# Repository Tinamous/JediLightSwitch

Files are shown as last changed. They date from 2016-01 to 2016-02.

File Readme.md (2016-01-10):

Jedi LightSwitch
================

The Jedi Light Switch is a home automation light switch which responds to the Jedi wave or touch(1). It aims to bring the humble wall switch into the modern WiFi lighting era.

1) Automation of modern WiFi lamps (LIFX/Hue) doesn't work if the lamp is switch off at the wall switch.
2) Existing switch may not work as expected for visitors with WiFi bulbs. Often the switch is on but the light off.
3) Switching the lights on/off via an app is annoying.
4) The wall switch may be difficult or impossible to replace with a automation friendly version. (Excludes the Jedi Lightswitch :-) )
5) The existing switch is single use, it switches on or off the main light. In a modern house their are many things this switch can be doing.

The Jedi Light Switch is PCB based with a custom 3D printed enclosure. It is powered by a Particle Photon which uses WiFi and optionally cloud services (i.e. IFTTT.com / Tinamous.com) to control and monitor the room environment.

The Photon may be user programmed so the switch may be heavily customised as desired, even OTA after installation. Likewise lighting control via IFTTT may be modified at will.

As well as acting as a switch it also acts as a room sensor with built-in temperature, humidity and light level measurements which may be used for further automation tasks.

Proximity detection allowing the sensing if somebody is close to the switch. (e.g. Switch the lights on in the room if they are not and somebody is close to the switch as they are probably about to try and switch them on anyway).

Two LEDs controlled by the Photon give the immediate feedback (cloud sevices may take a few seconds to perform the apporpiate operations), these LEDs may also be internet controlled to draw attention to something (i.e. the doorbell ringing).

Why:
----
If you have LIFX or Hue lights they stop working once somebody switches them off at the wall switch which can ruin your automation plans. The Hue has a small switch however the LIFX lights rely on 3rd party products for switching, both suffer from our built-in tendandy to switch the light off at the switch as we leave the room. Neither lights work so well when that happens! Neither Hue or LIFX switch options are immediatly obious that they should be used in preference to the wall switch. Nobody wants to have to train their guests how to switch the lights on or off.

Imaging the scene. You walk into your room, the lights are off but the light switch is on.
* Option 1: Switch the light switch off then on again. This works a charm (but only for the main light).
* Option 2: 
** Find your phone (hopefully it's not somewhere in the dark room you are walking into)
** Unlock your phone
** Launch the LIFX application
** Wait whilst the LIFX applicaiton loads
** Try not to trip or walk into anything as you've continued to walk whilst working your phone in the darkened room
** Scroll to the bulbs or scene you wish to set
** Select the bulbs or scene
** Hopefully the lights respond first time, if not wait a bit and try again
** Put phone away
** Think how great it is you can control your lights from your phone...

Leaving a room:
---------------
Nobody likes to leave the lights on in rooms that are unused or when you go out.....

Imaging you leave the room.
* Option 1: Flick the light switch to switch the light off (goodbye automation).
* Option 2: Find your phone, unlock your phone (you see where this is going).

Neither of these senarios are great. You could replace or remove the light switch...

The Light Switch Problem:
-------------------------
* In the UK we have a different style and voltage requirement for light switchs compared to USA, hence home automation products are slow (if ever) to reach the UK market.
** This is not helped by the need for a CE mark which is slow and expensive.
** Often the switches that are available are extreamly cheap (I've had 5x £30 switches fail when the incandecent bulb blew).
* Most HA light switches require a minimum of 25mm backing box. A lot of UK homes use a 15mm box which either means you need to pad the switch out on the wall (ugly) or replace the box (painful).
* A lot (almost all) HA light switches require "3 wire" configuration. Live, Neutral and switch return. Most UK homes have only 2 wire switches (Live and return).
* Not everybody wants to play with the electrics to get a fancy light switch fitted or pay for an expensive electrician.
** If it's a 2 wire replacement this isn't too difficult, changing the 2 wires to 3 and/or replacing the backing box are a big job.
* If you rent chances are you are not allowed to replace the light switch anyway. Who wants to get thrown out of their rented accomodation for a bit of home automation goodness!
* Switching the lights off at the light switch ruins automation.
* The light switch generally only controlls the main light, occasionally wall lights.
* Switching the wall switch on or off doesn't tell your home automation system that the action has happened so no further actions can happen based on that.
* Theirs no intelligence in the on/off of the humble wall switch. If you walk into a room when you're still half asleep having the light come on at 100% brightness is painful.

The Solution:
-------------
The Jedi Light Switch is designed to remove those problems through a two part solution. The main part is the touch and gesture sensitive WiFi based switch PCB, the second is the enclosure.

The switch and enclosure are designed to be simple to install, no re-wiring required (except for external USB power), a direct replacement for the humble wall switch whilst leaving the switch in place, just hidden behind some sexy technology.

The current enclosure is designed to fit over a UK light switch (sorry rest of the world, It may work in Europe, it certainly won't fit over USA switches). 

The enclosure is 3D printed in two parts:

1) The base. This has an overlap area that fits between the wall and the existing switch to secure the base in place and only requires the switch to be loosened and not removed.
** To fit loosen the screws on the light switch slightly so that the switch comes forward about 2mm.
** Slide the base down the wall so the back fits between the wall and the switch until the top of the switch is as close to the top of the base as it can go.
** Tighten the switch screws, ensuring the enclosure is level. This clamps the base part to the wall. No other fixing is required.
2) The cover:
** This is optional. You may if you wish attach the switch PCB via glue or screws to the base and be done.
** The cover gives a nicer finish to the switch whilst also providing mechanical fixing of the PCB within the base. It may be printed in any colour you can get the 3D filament or resin for, although clear works well.
** Optional: You may also print on a clear "acetate film" to fit between the cover and the PCB with a nice pattern or design over the touch sensor.
** The cover simply slides over the base with the PCB in the middle and stays in place by friction making it easy to remove should you need access to the actual wall switch.

Other Advantages:
* Use of gesture to switch the lights on would work well in dirty/wet areas (e.g. the kitchen) where you may not wish to touch something (e.g. you've half way through cooking chicken).
* The switch supports up, down, near and far waves as well, these may be used to dim the lights, control additional (hall/landing) lighting or something else.
* You don't actually need an existing light switch. The case could be directly attached to the wall or something else to provide easy additional lighting points.
* Other than a USB power pack and WiFi no other external parts are required (no Hub, no dedicated lighting wiring, no ......, not even screws or double sided sticky tape)
* You don't have to be British (but it helps). The switch enclosure and PCB are sized to cover a UK light switch, however as they can be used in stand-alone mode they don't have to be used with a UK switch.
** The SCAD design for the enclosure is provided which may be modified to fit other requirements.
* Intellegent:
** The lights could be dimmed to brightness greadually, especially if the switch knew the room was very dark previously.
** or set to automatically switch off or dim the lifhts after 2 hours.
** or the air-con switched on if the room is hot and humid and the lights have just been switched on (or off).
** the curtains could be closed automatically when the lights are switched on.
** the whole house lights could be switched off if the hall light was switched off (and vica versa, house lights switched on when it's dark when hall/door switch is switched on).

Limitation:
-----------

* Currently requires external USB 5V DC power as the Photon is relativly fairly power hungry device (i.e. using WiFi). Even if a battery was fitted it would require a fair size and to be topped up regularly particularly if the switch is required to respond to network actions (e.g. light LEDs, update firmware etc.).

* Lack of a traditional switch mechanism which may confuse guests. Hopefully the touch ability would be enough to make up for this.

* Cloud services can be slow. Using Photon -> Particle.io -> IFTTT -> LIFX.com -> LIFX bulb can be seconds in the trip which is not idea for a light switch. In this time a new user may have told the switch to switch on/off/on/off/on etc a number of times.

Future upgrades:
----------------

Planned for V1.1:
* 2 LEDs in the bottom corners to match the top so each corner has an LED.
* Back lighting. Adding more LEDs to project backwards to light up the enclosure (works best for clear enclosures). Ideally NeoPixel type so they can be controlled from 1 wire and have a range of colour / intensity controlled.

Future posabilities:
* Split/Dual touch sensor pads so that it works for hall/landing lights (up/down) or duel lighting modes in a room (main/wall lights).
* RS485 interface, supply 5V to Photon from a RS485 with 12V house wired RS485 network, interface with other RS485 HA devices and provide a more reliable connection and power.
** This is easier then putting a PoE Ethernet connection on the switch.
* Battery + charger
* Improved interrupt's that can be used to wake the Photon (currently 2 interupts, one high and one low which can't both be used to wake the Photon) to improve battery life.
* Buzzer
* IR Sender to allow the switch to send out instructions from automation requests (e.g. telly on) or relay the signal from room to room.
* IR Receiver to allow remove control of the switch and/or transmission from room to room.
* Microphone (to decect noise levels rather than listen).
* PIR sensor
* Improved temp/humidity sensor for one of the new Bosch line with BP and gas sensing as well.

License:
--------
Licensed under Creative Commons ShareAlike 4.0 https://creativecommons.org/licenses/by-sa/4.0/

Restrictions: May not be used to control lighting on a death star.

Notes:
------
1) Also responds to non-Jedi waves and touch. Not to be used where control by non-Jedi personel is restricted.

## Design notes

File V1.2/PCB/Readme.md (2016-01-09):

Jedi LightSwitch PCB.
=====================

Licensed under Creative Commons ShareAlike 4.0 https://creativecommons.org/licenses/by-sa/4.0/

PCB Fabrication by OSH Park.
PCB: <TODO: Insert PCB link>

PCB Stensil by OSH Stencil (https://oshstencils.com/).

PCB Assembly Notes:
-------------------
APDS-9960 and HTU21D are tricky components to solder onto the board. The switch may be used without them if you wish to not solder them and prefer to use touch only.

Use either a hot air gun for solder reflow or reflow oven for the top layer. Use a stencil from OSH Stencils and place U1/U2 (APDS-9960 and HTU21D) carefully. 

Using a low flow and a temperature appropriate for the solder paste heat the board around U1/U2 bringing until the solder melds. Allow a little longer for U1 as the solder is not visible.

The bottom of the board should be hand solderered to prevent U1/U2 dropping off. Most parts are 1206 or 0805 and not overly difficult. U4 (AT42QT1010) is a little difficult but excess solder can be removed with solder wick if needed.

The value of C4 may need to be adjusted to increase/reduce sensitivity. 10nF was found to be to little. 68nF was overly sensitive.

The value of R5/R6 should be selected based on the required brightness of the LEDs and the LED selected.

Resources:
----------
SparkFun Eagle Library and breakout boards used under CC-SA.

SparkFun Eagle Library: https://github.com/sparkfun/SparkFun-Eagle-Libraries

SparkFun APDS-9960 breakout: https://www.sparkfun.com/products/12787
SparkFun HTU21D breakout: https://www.sparkfun.com/products/12064
SparkFun AT42QT1010 breakout: https://www.sparkfun.com/products/12041

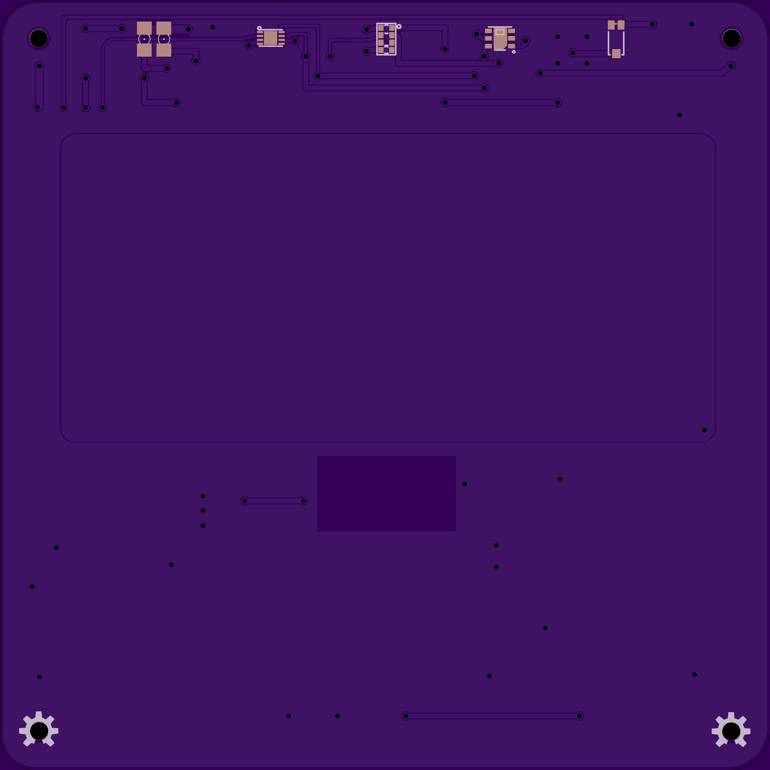
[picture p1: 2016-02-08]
V1.2/PCB/JediLightSwitch-1.2-Top.png

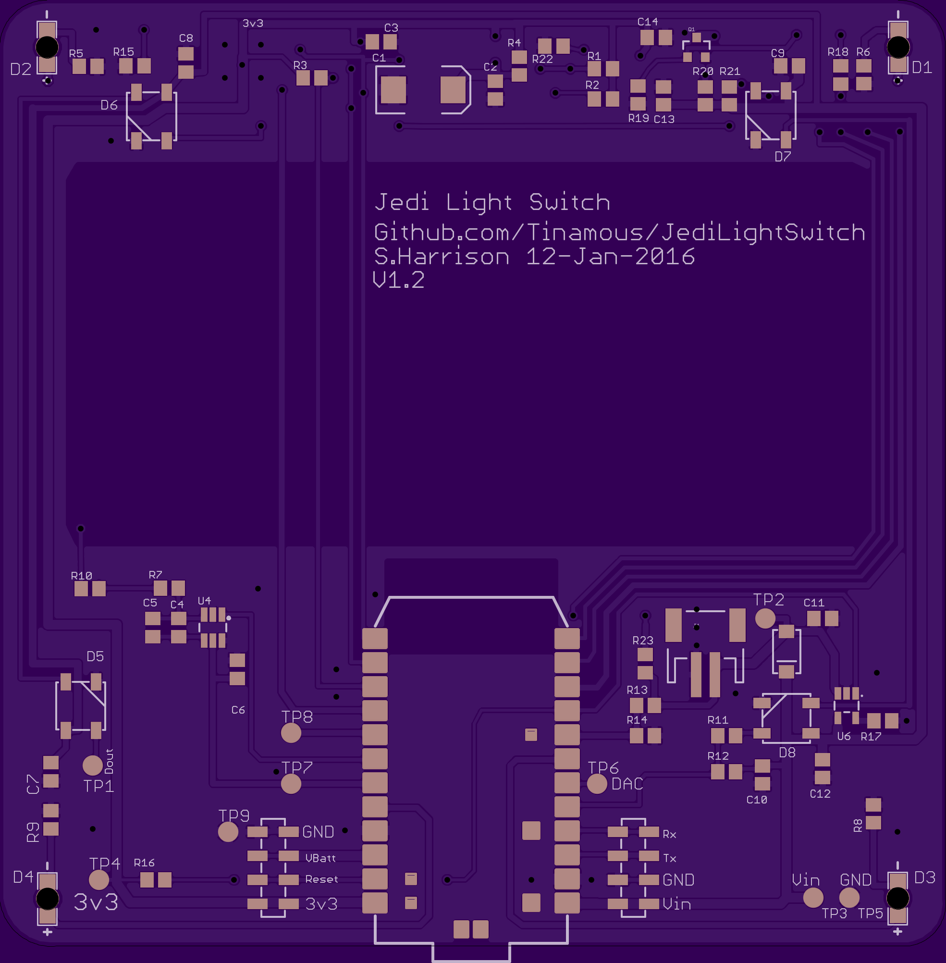
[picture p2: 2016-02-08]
V1.2/PCB/JediLightSwitch-1.2-Bottom.png

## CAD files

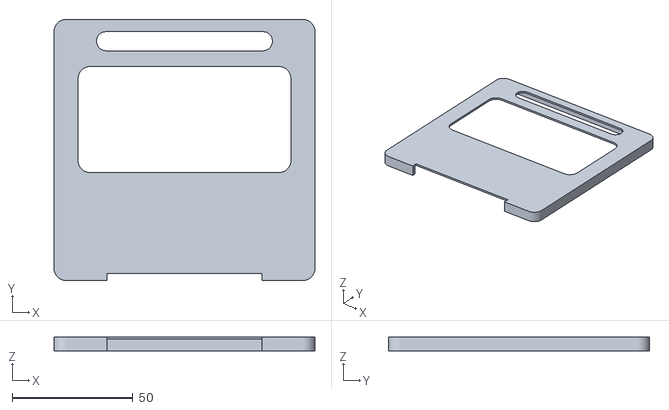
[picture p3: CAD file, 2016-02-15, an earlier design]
V1.1/Enclosure/Cover-5mm-V1.2.stl
108.2 x 108.2 x 6.00

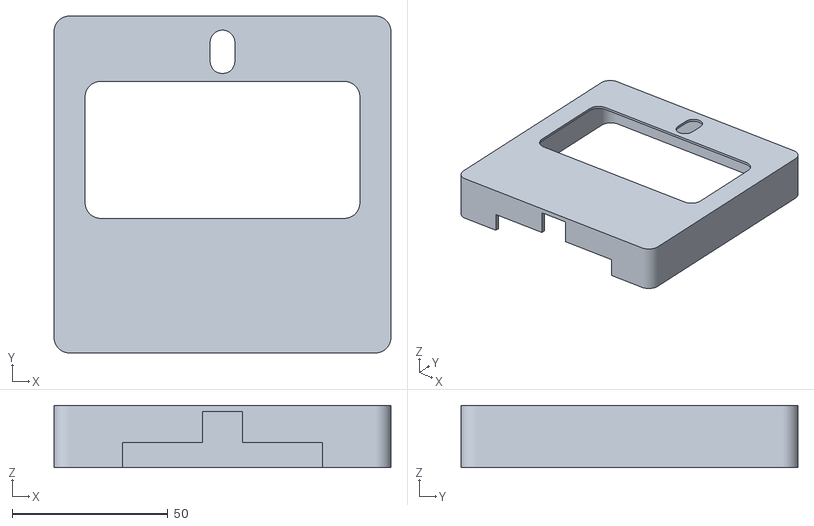
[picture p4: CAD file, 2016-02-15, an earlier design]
V1.1/Enclosure/Cover-19mm-V1.1.stl
108.2 x 108.2 x 20.0

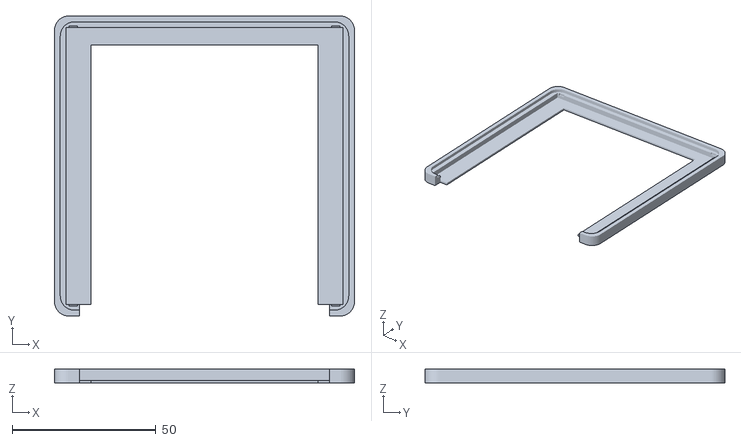
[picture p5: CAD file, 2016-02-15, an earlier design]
V1.1/Enclosure/Base-5mm.stl
104.2 x 104.2 x 5.00

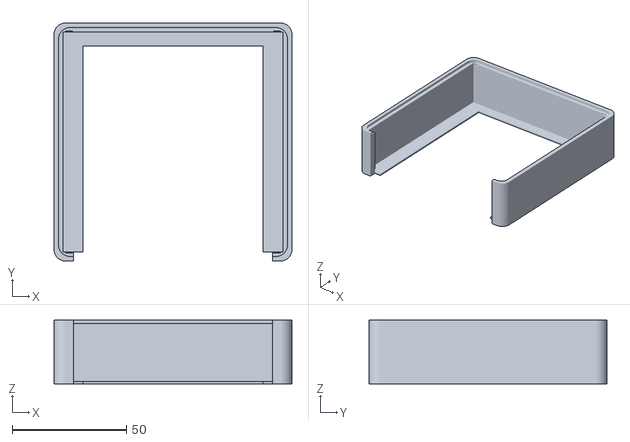
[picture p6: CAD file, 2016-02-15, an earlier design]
V1.1/Enclosure/Base-28mm.stl
104.2 x 104.2 x 28.0

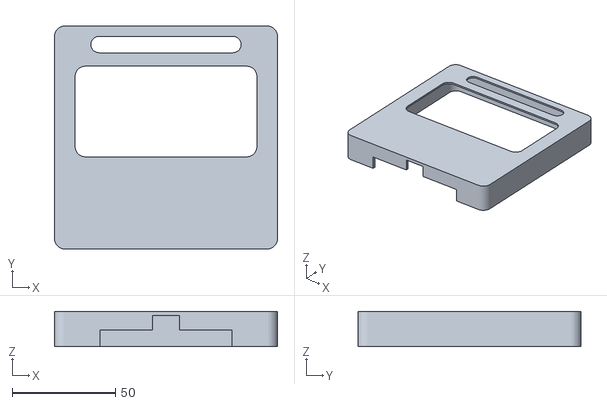
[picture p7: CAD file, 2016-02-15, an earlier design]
V1.1/Enclosure/Cover-16mm-V1.2.stl
108.2 x 108.2 x 17.0

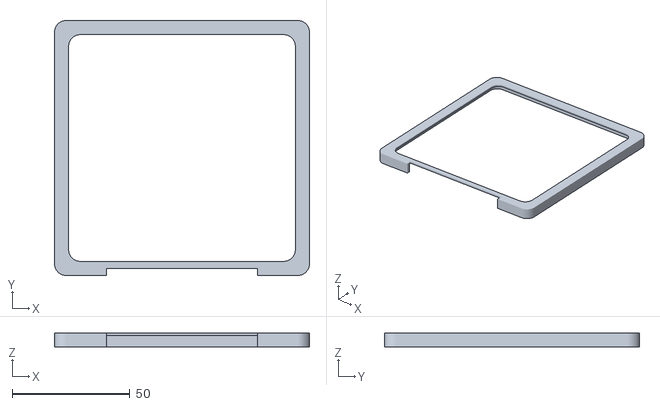
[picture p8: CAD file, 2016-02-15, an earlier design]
V1.1/Enclosure/Cover-5mm-minimal.stl
108.2 x 108.2 x 6.00

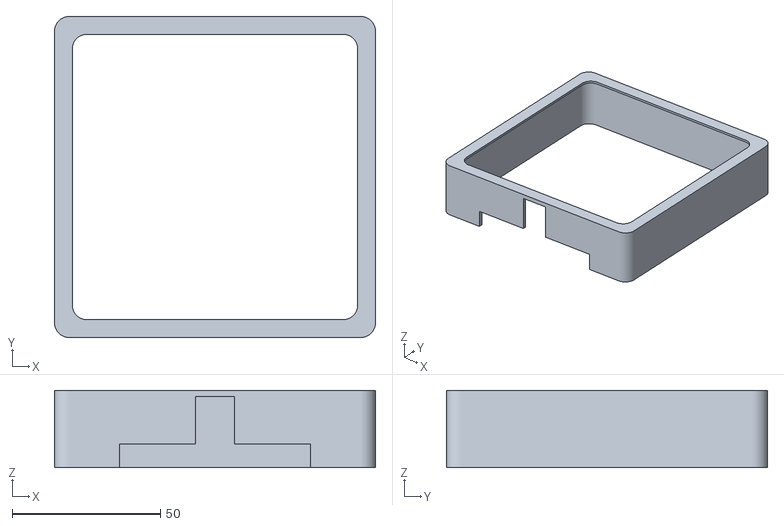
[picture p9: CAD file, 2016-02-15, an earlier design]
V1.1/Enclosure/Cover-25mm-minimal.stl
108.2 x 108.2 x 26.0

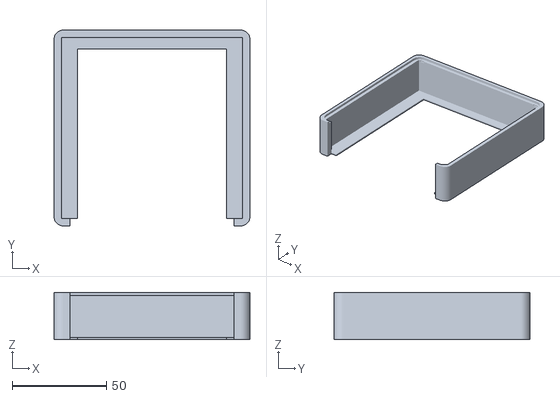
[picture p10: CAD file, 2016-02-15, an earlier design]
V1.1/Enclosure/Base-25mm.stl
104.2 x 104.2 x 25.0

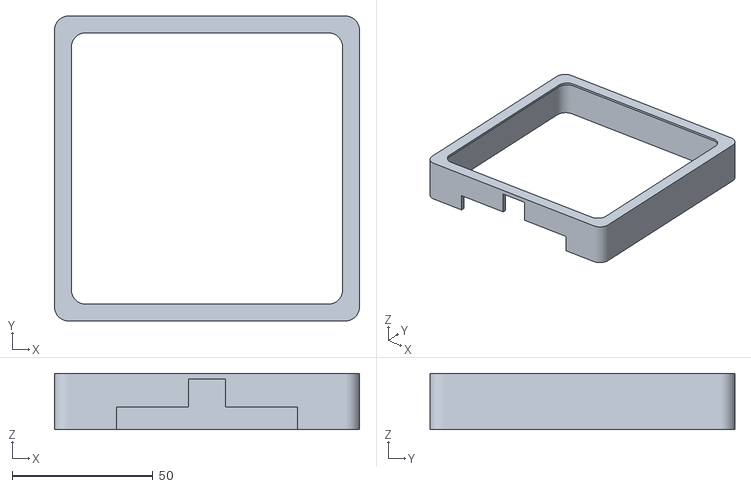
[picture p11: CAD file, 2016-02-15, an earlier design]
V1.1/Enclosure/Cover-19mm-minimal.stl
108.2 x 108.2 x 20.0

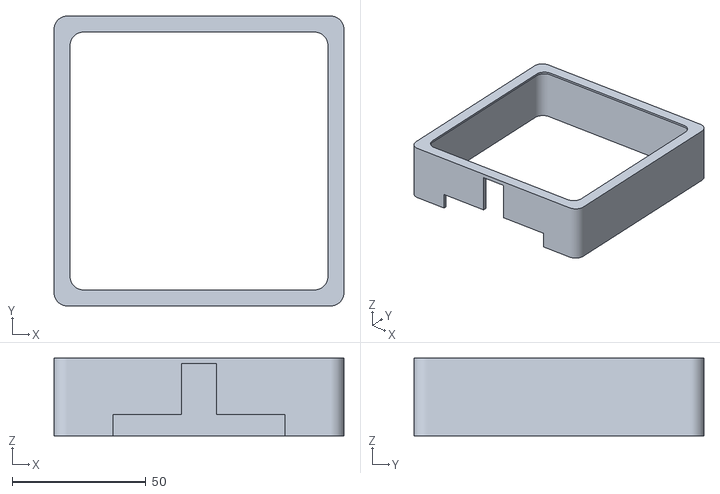
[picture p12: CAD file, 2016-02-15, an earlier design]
V1.1/Enclosure/Cover-28mm-minimal.stl
108.2 x 108.2 x 29.0

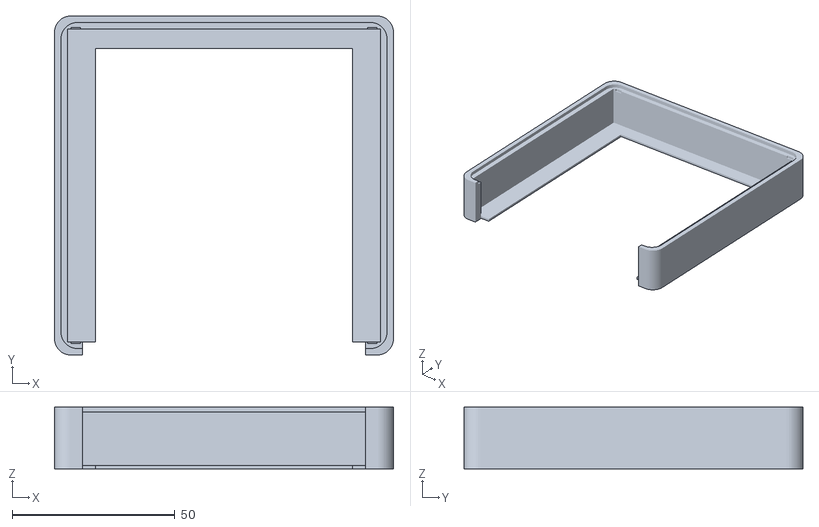
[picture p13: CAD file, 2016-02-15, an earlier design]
V1.1/Enclosure/Base-19mm.stl
104.2 x 104.2 x 19.0

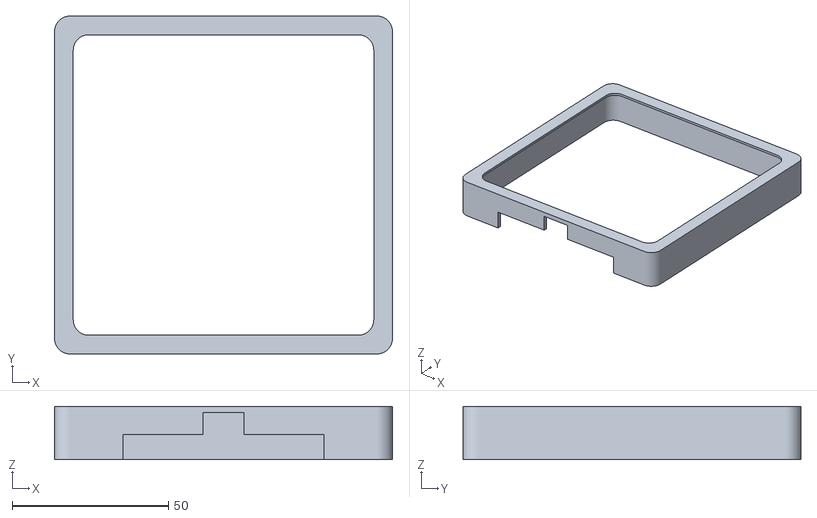
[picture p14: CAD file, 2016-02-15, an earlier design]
V1.1/Enclosure/Cover-16mm-minimal.stl
108.2 x 108.2 x 17.0

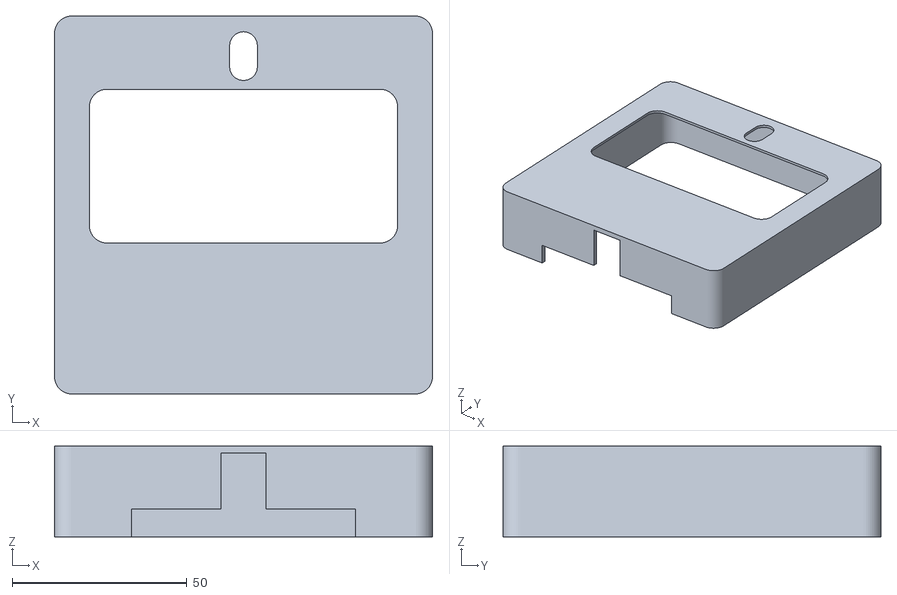
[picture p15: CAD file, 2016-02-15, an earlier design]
V1.1/Enclosure/Cover-25mm-V1.1.stl
108.2 x 108.2 x 26.0

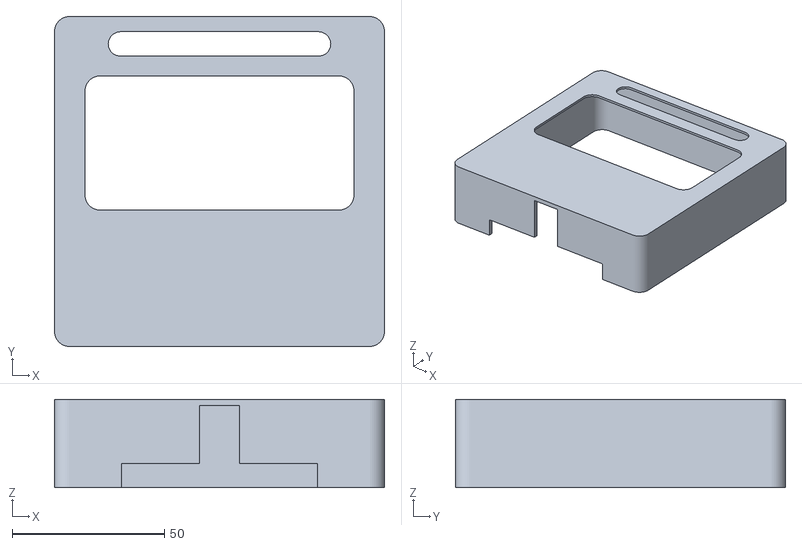
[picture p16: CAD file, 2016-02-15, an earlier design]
V1.1/Enclosure/Cover-28mm-V1.2.stl
108.2 x 108.2 x 29.0

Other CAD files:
V1.1/Enclosure/Cover-5mm-V1.1.stl
V1.1/Enclosure/Cover-16mm-V1.1.stl
V1.1/Enclosure/Cover-28mm-V1.1.stl
V1.1/Enclosure/Cover-25mm-V1.2.stl
V1.1/Enclosure/JediLightSwitch.scad
V1.1/Enclosure/Base-16mm.stl
V1.1/Enclosure/Cover-16mm.stl
V1.1/Enclosure/Cover-19mm-V1.2.stl
V1.1/Enclosure/Cover-19mm.stl
V1.1/Enclosure/Cover-25mm.stl
V1.1/Enclosure/Cover-28mm.stl

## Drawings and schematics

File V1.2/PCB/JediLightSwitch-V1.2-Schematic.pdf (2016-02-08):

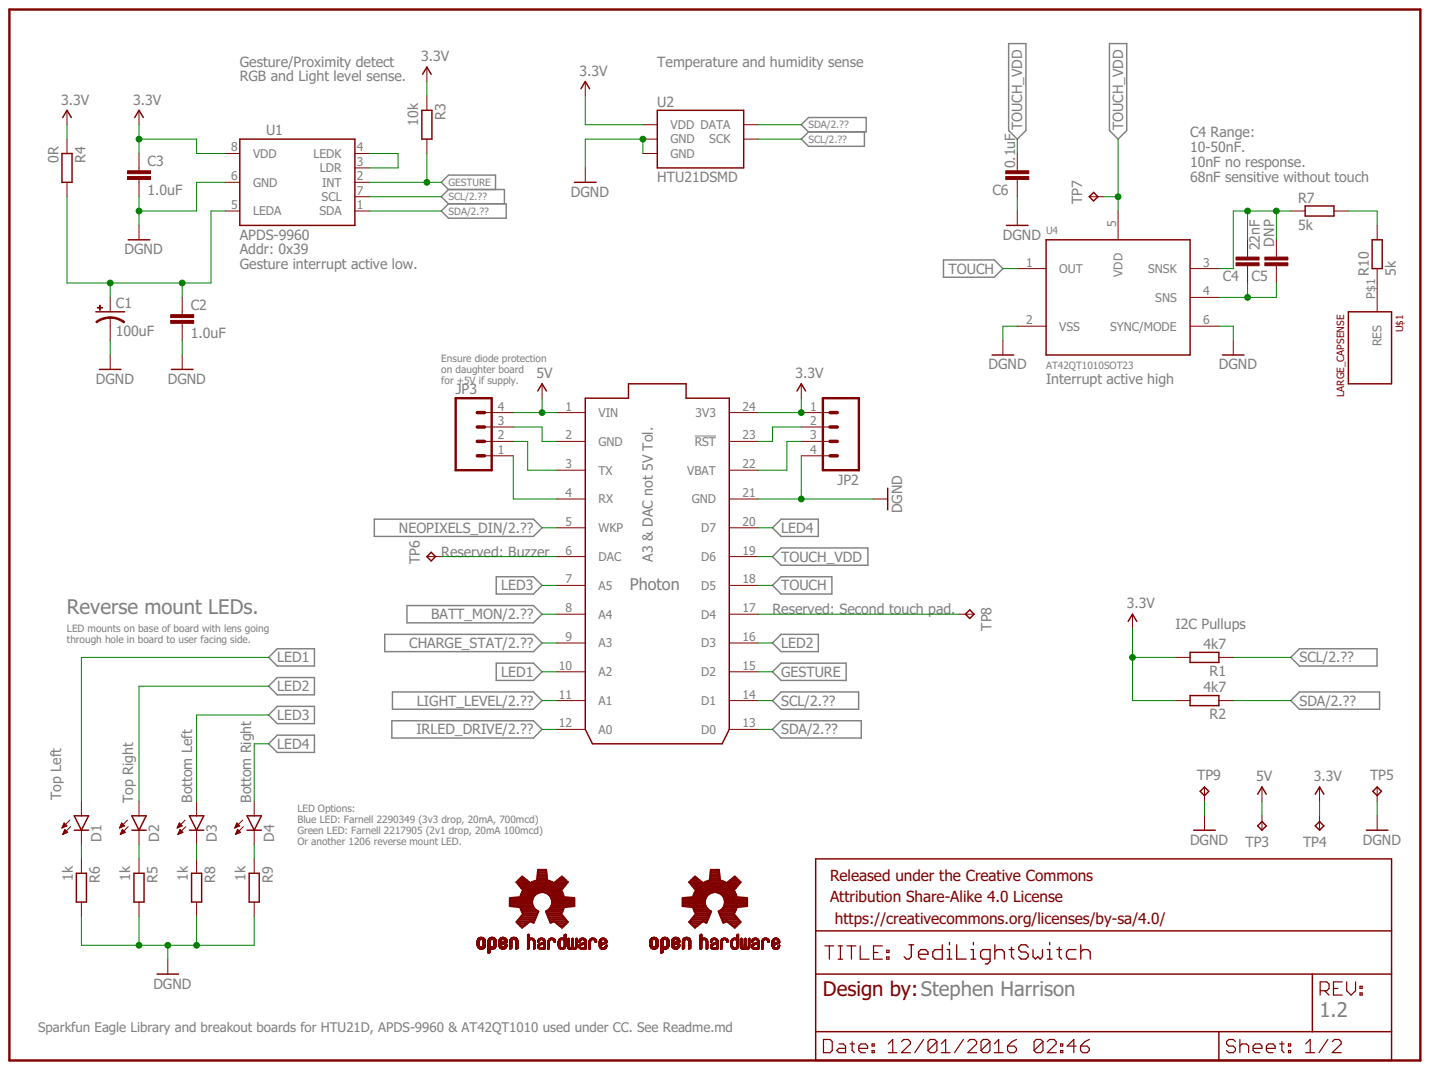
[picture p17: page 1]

C4 Range: 10-50nF. 10nF no response. 68nF sensitive without touch

LED mounts on base of board with lens going
through hole in board to user facing side.

Top Left Top Right Bottom Left Bottom Right

LED Options: Blue LED: Farnell 2290349 (3v3 drop, 20mA, 700mcd) Green LED: Farnell 2217905 (2v1 drop, 20mA 100mcd) Or another 1206 reverse mount LED.

Released under the Creative Commons Attribution Share-Alike 4.0 License https://creativecommons.org/licenses/by-sa/4.0/

Sparkfun Eagle Library and breakout boards for HTU21D, APDS-9960 & AT42QT1010 used under CC. See Readme.md

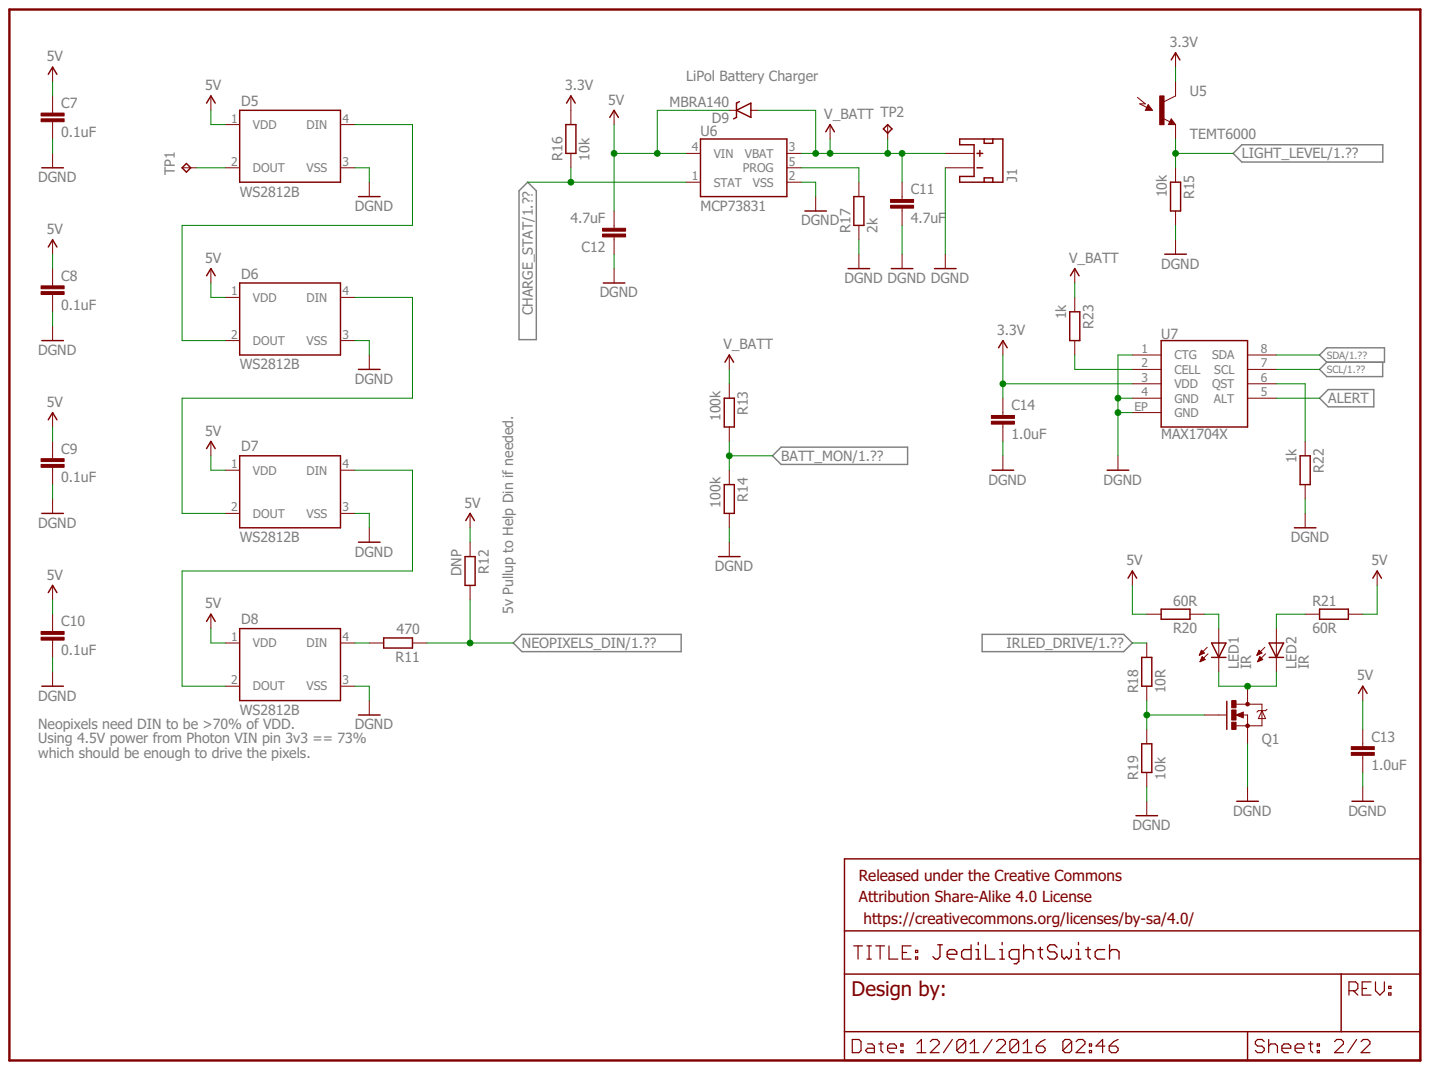
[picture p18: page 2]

5v Pullup to Help Din if needed.

Neopixels need DIN to be >70% of VDD. Using 4.5V power from Photon VIN pin 3v3 == 73%

which should be enough to drive the pixels.

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

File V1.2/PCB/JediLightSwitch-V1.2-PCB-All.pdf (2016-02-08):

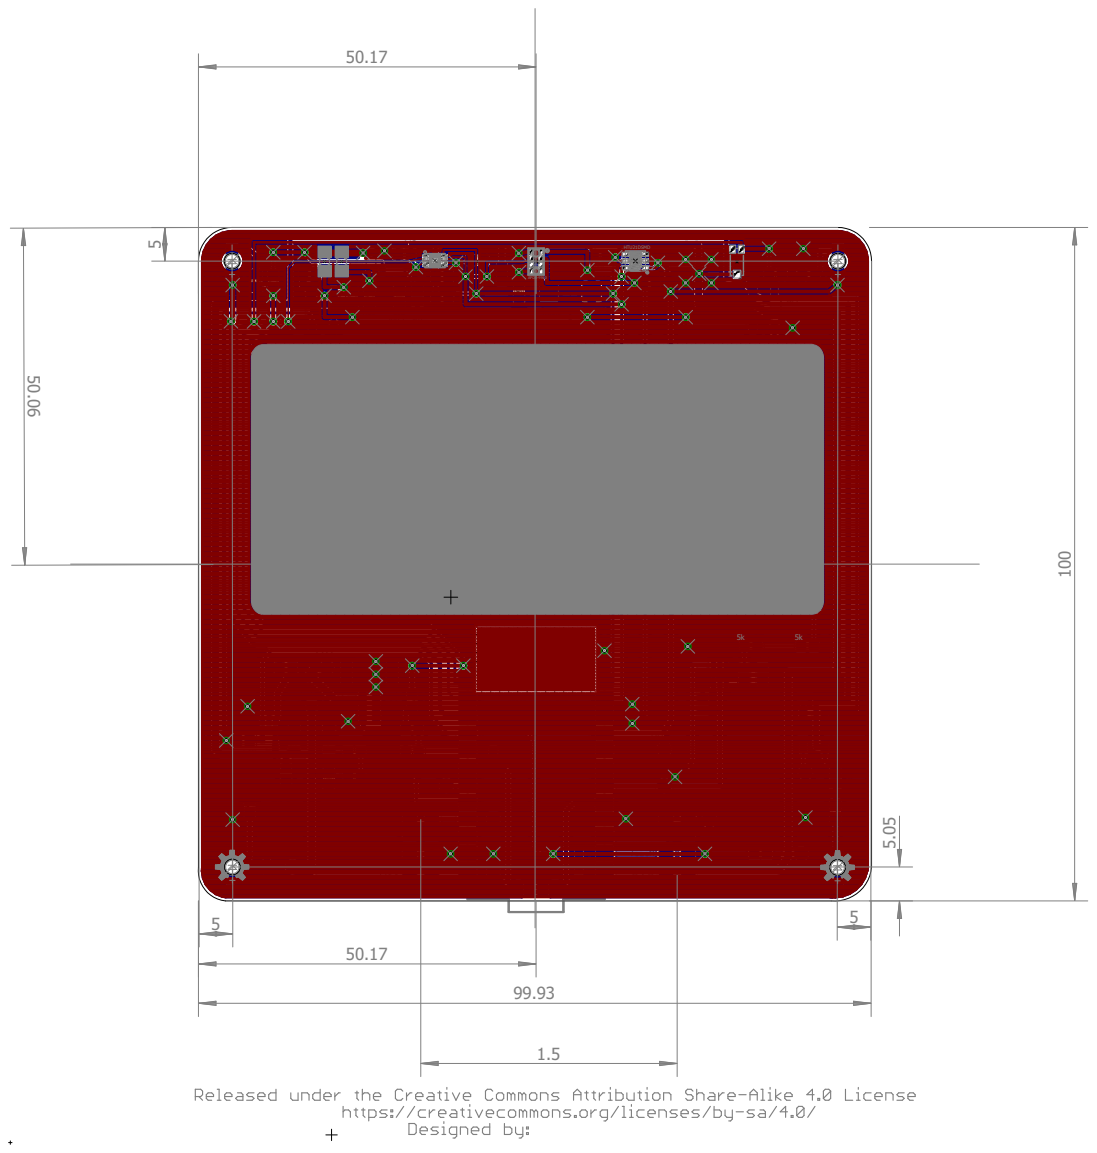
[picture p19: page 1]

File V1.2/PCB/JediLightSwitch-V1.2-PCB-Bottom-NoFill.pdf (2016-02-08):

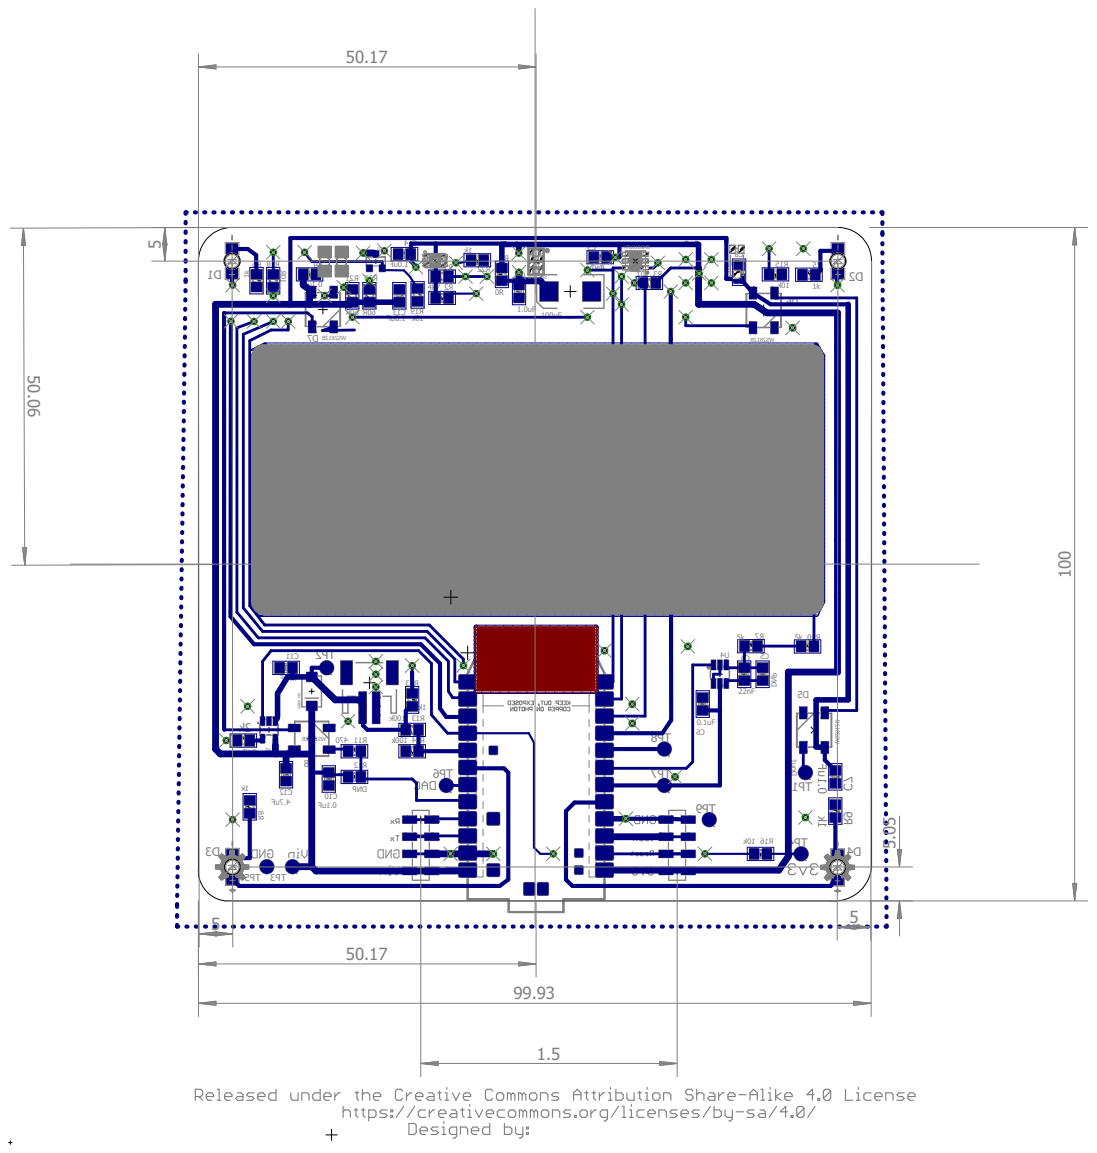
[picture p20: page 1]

HTU21DSMD

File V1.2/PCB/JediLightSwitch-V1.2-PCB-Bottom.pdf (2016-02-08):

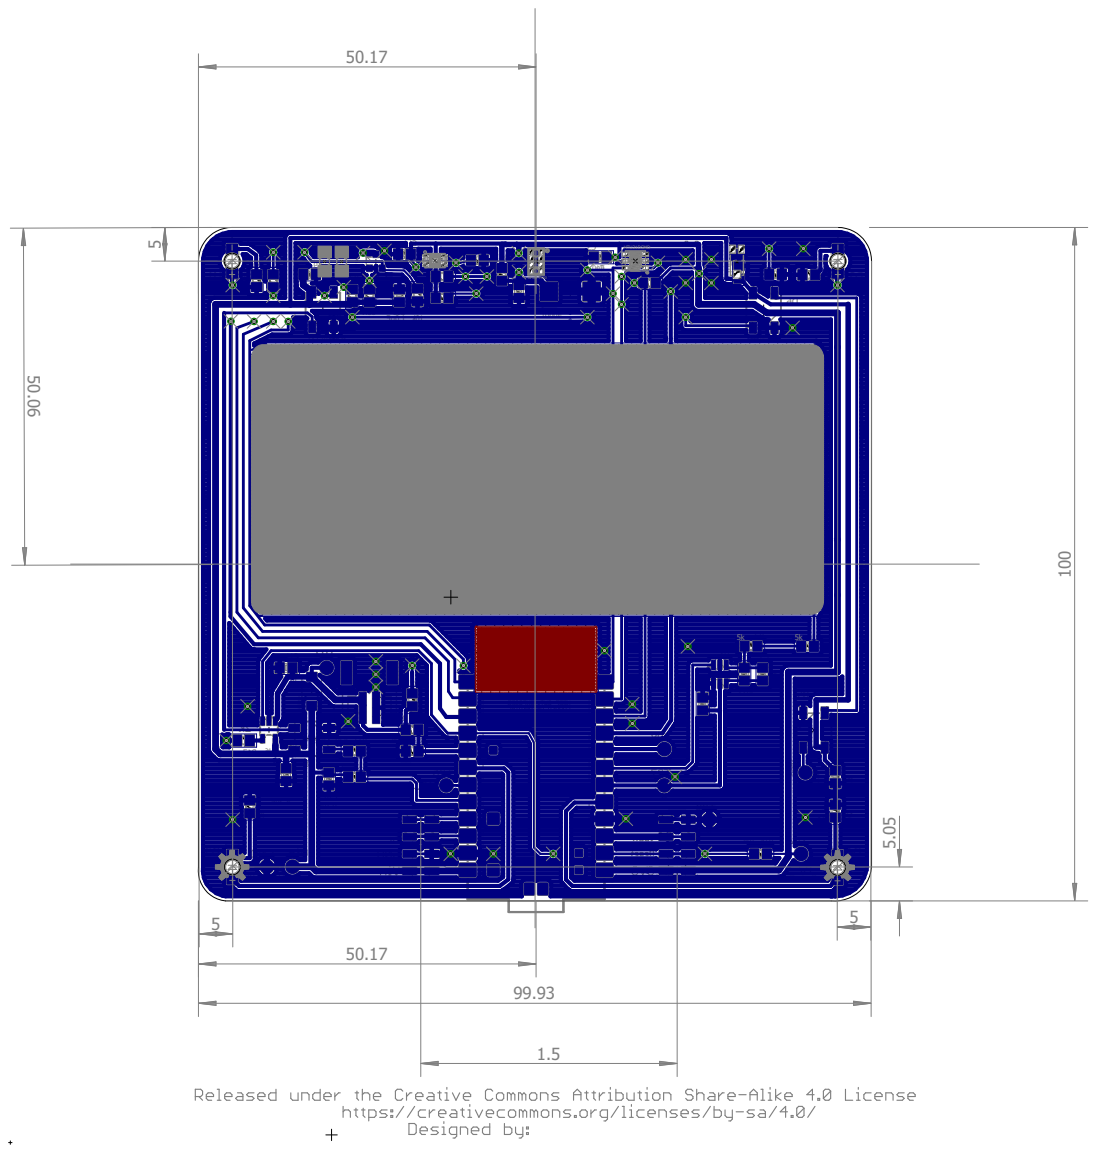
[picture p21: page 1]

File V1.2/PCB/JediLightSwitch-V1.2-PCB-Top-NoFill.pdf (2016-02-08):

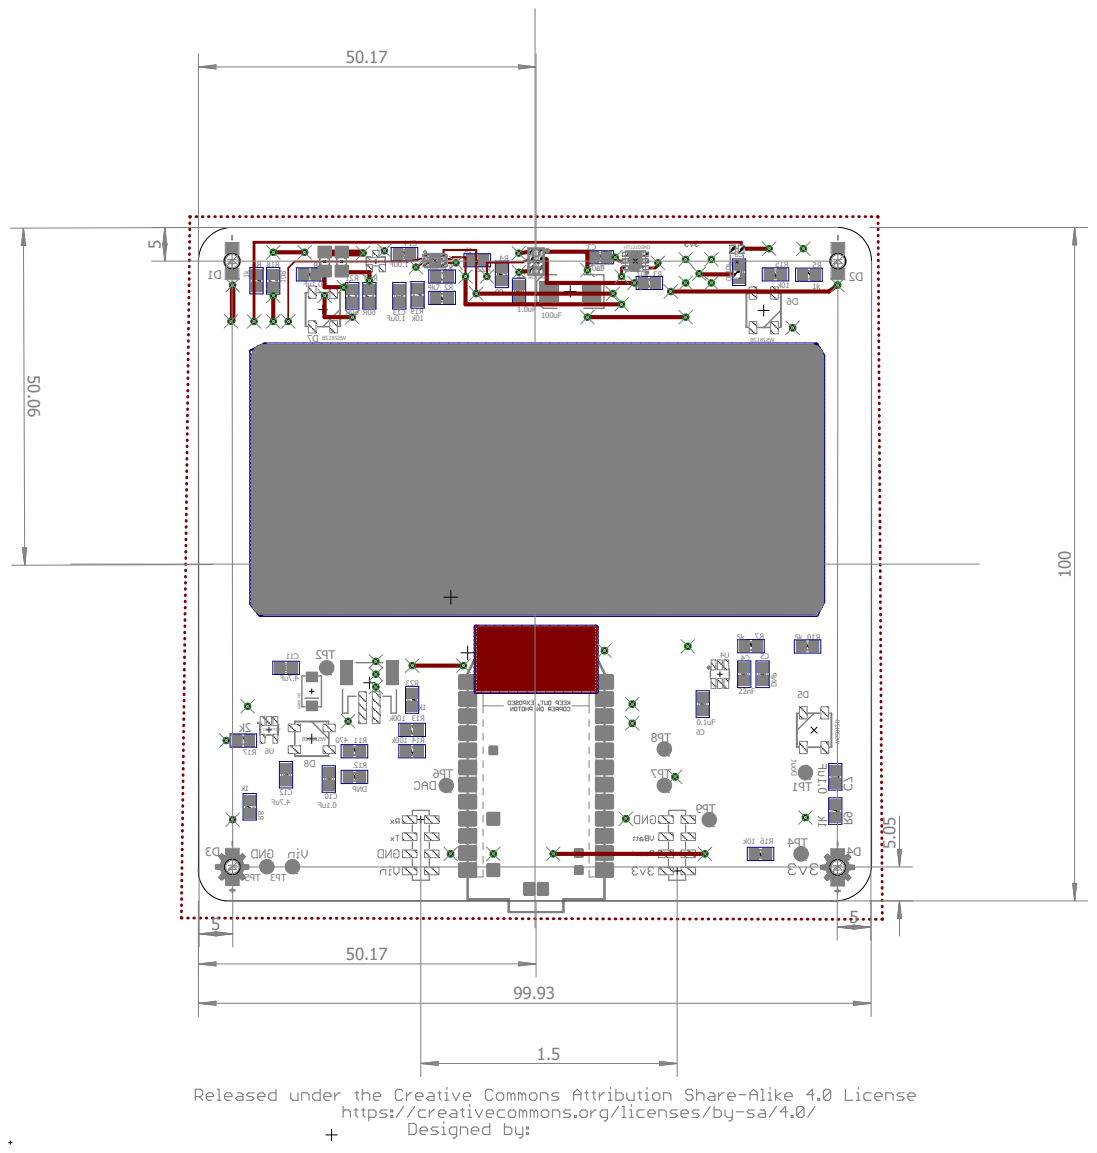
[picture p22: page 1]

HTU21DSMD

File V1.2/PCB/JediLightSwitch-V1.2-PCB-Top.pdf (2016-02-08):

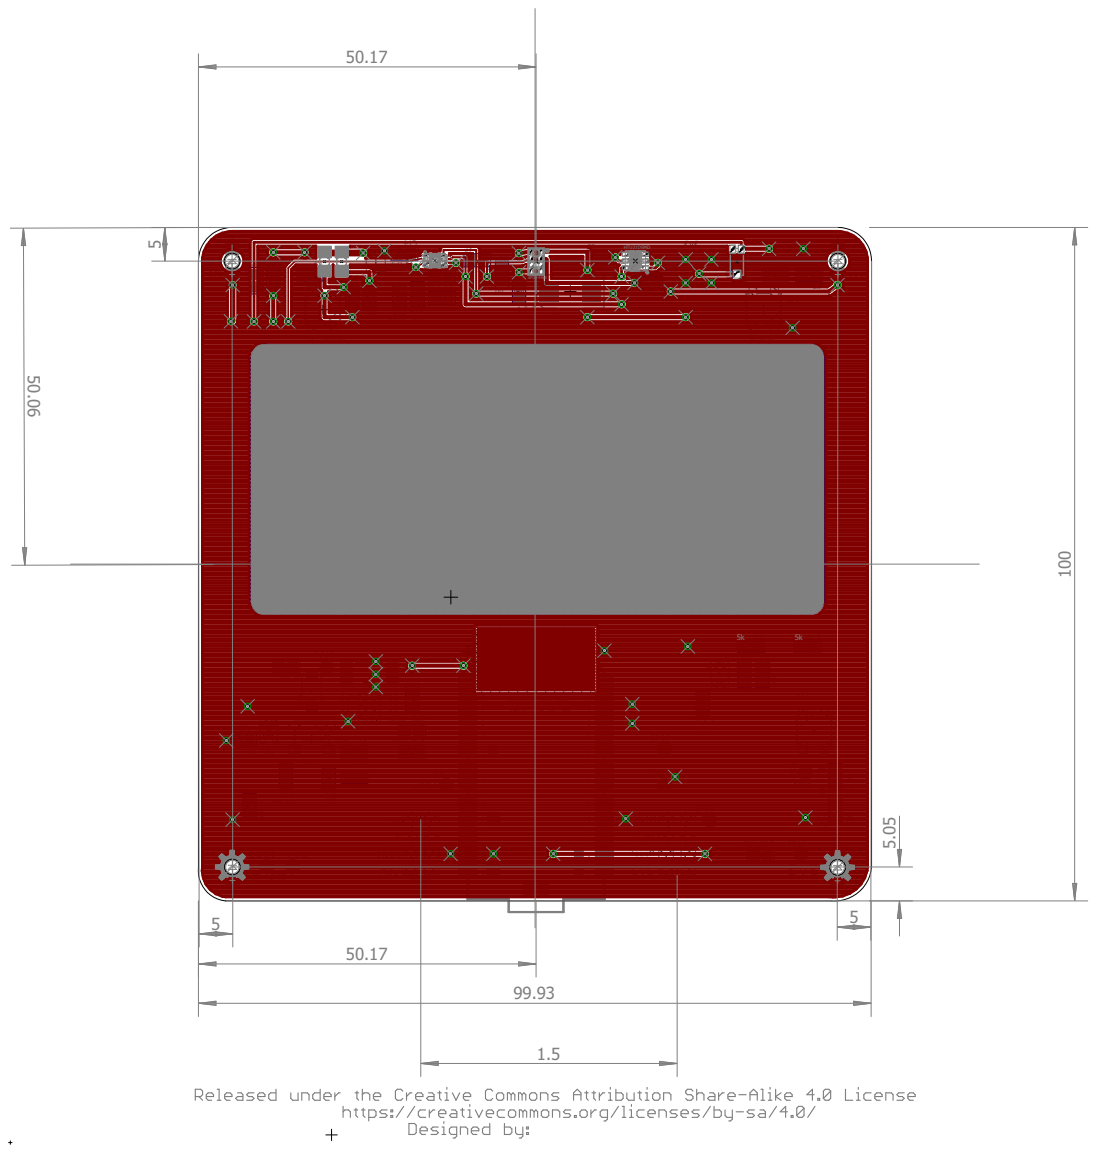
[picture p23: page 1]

HTU21DSMD

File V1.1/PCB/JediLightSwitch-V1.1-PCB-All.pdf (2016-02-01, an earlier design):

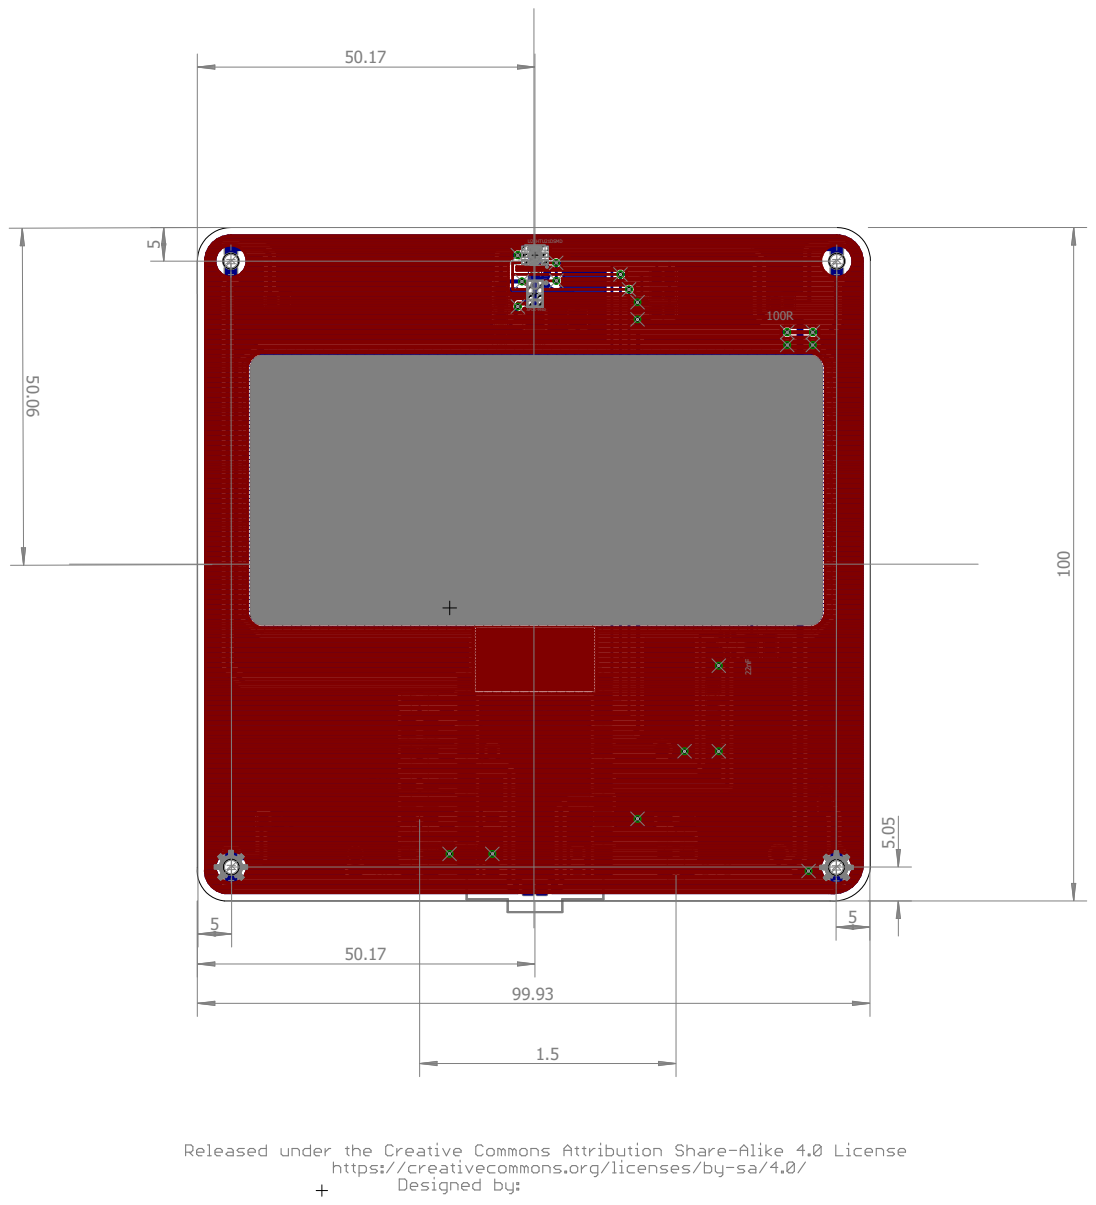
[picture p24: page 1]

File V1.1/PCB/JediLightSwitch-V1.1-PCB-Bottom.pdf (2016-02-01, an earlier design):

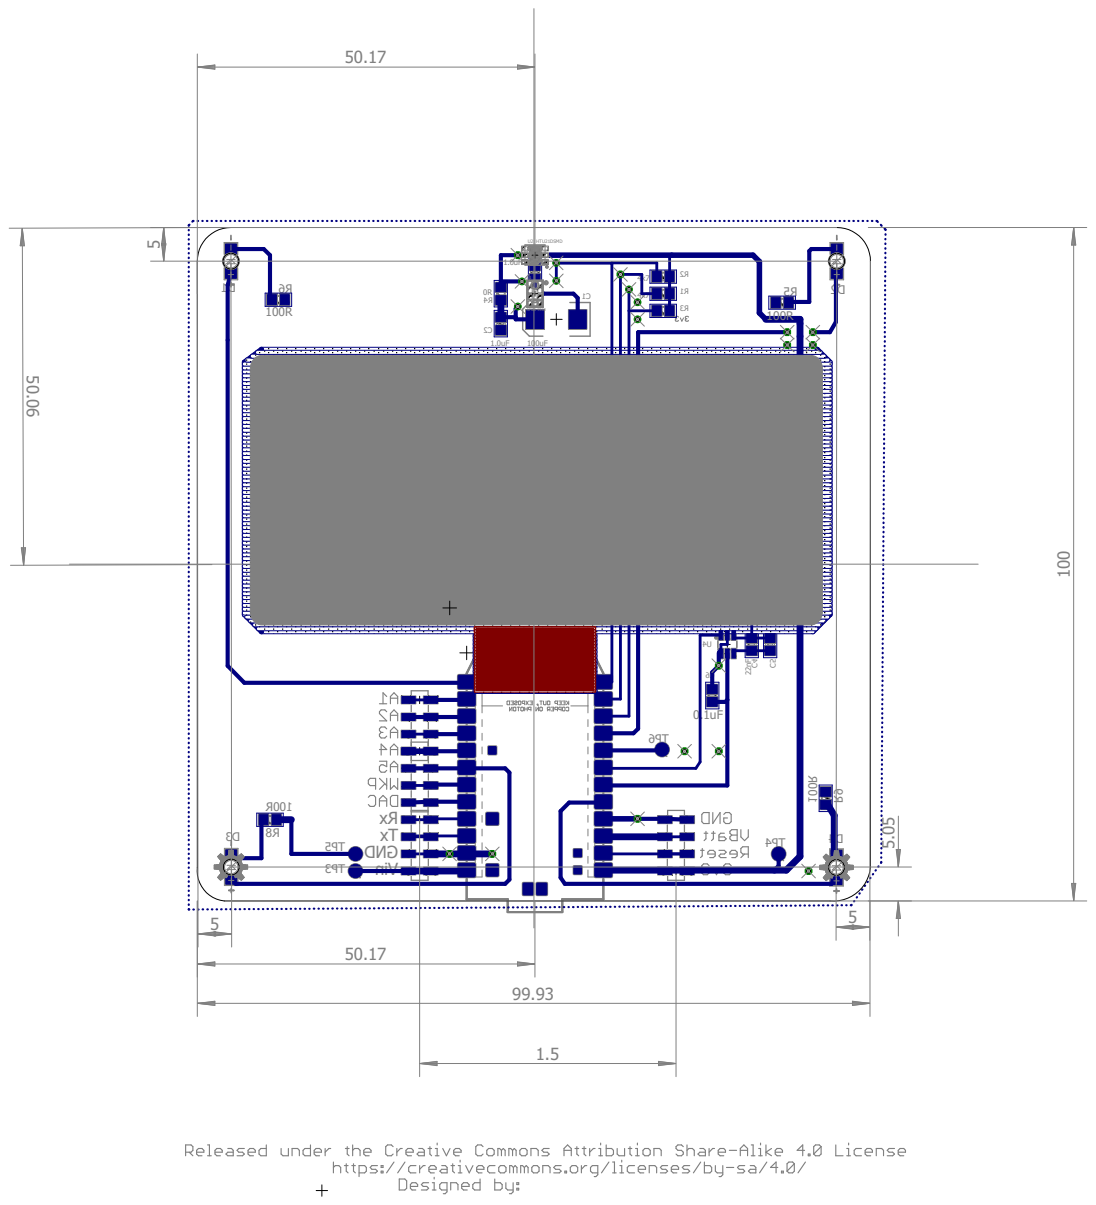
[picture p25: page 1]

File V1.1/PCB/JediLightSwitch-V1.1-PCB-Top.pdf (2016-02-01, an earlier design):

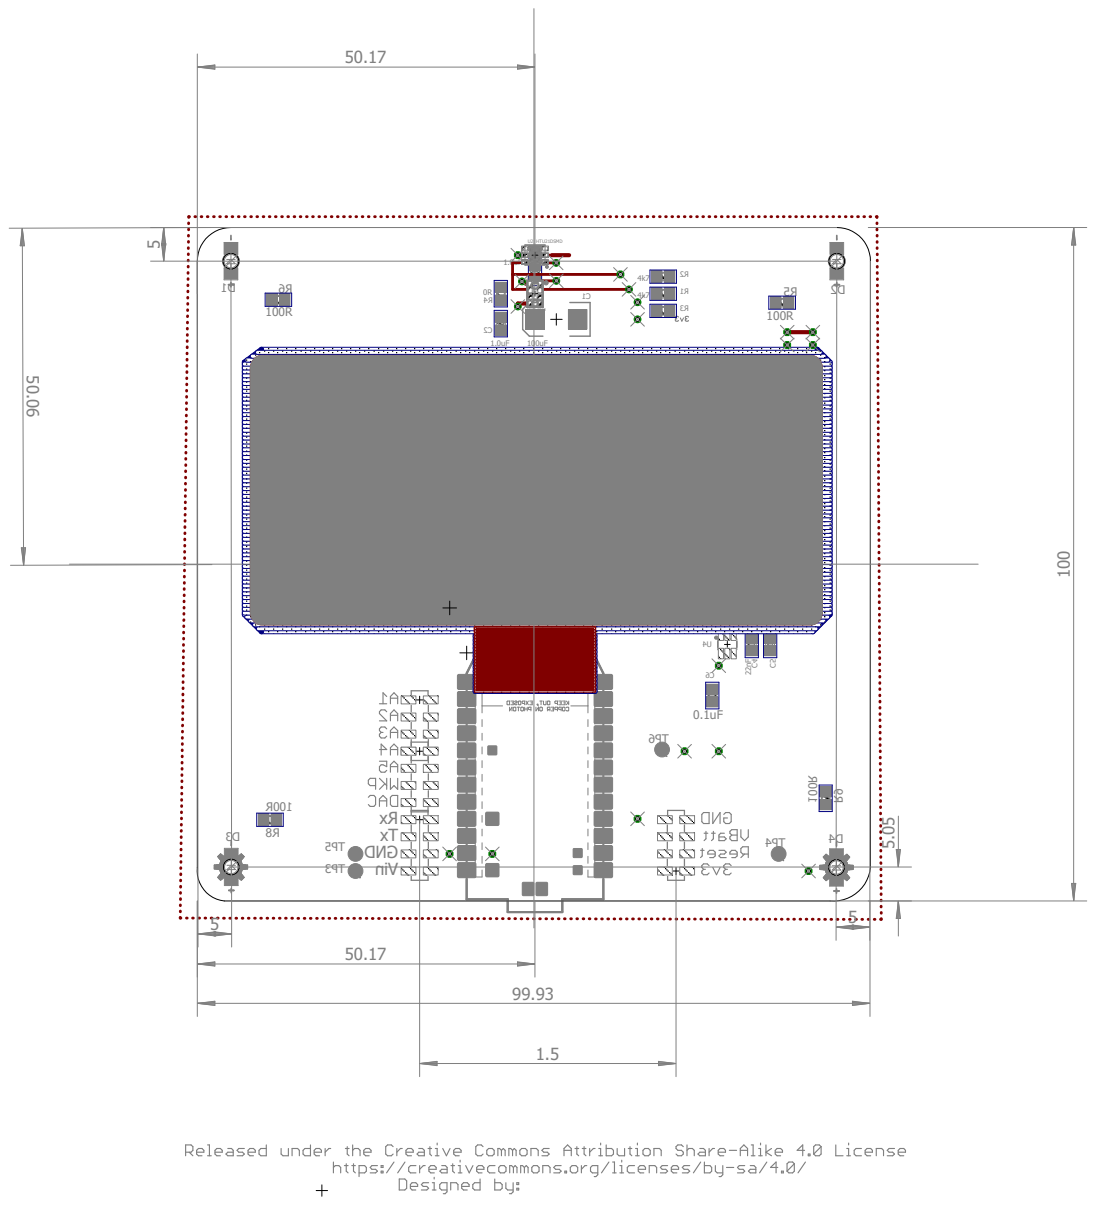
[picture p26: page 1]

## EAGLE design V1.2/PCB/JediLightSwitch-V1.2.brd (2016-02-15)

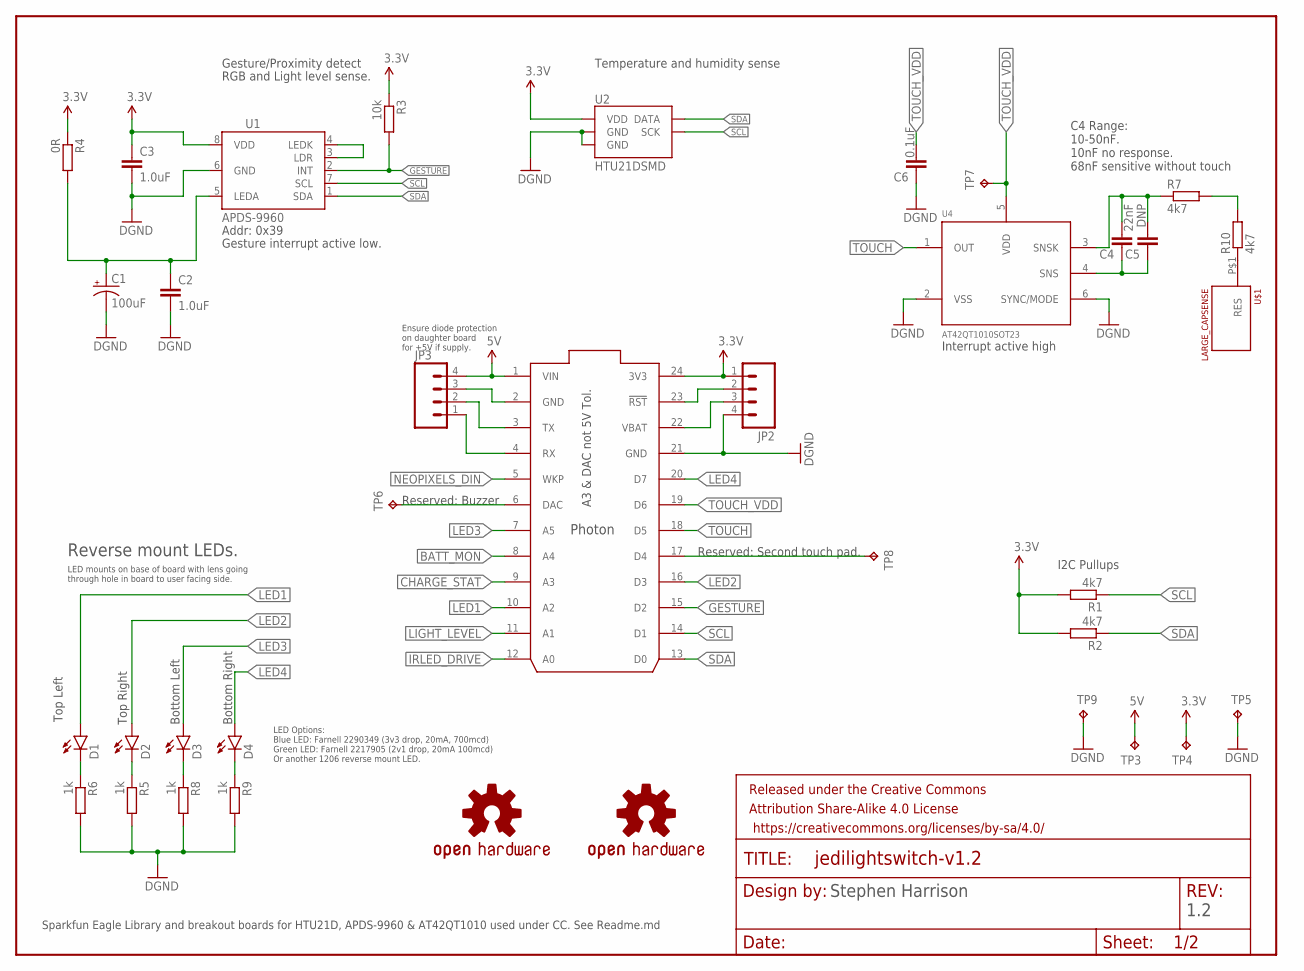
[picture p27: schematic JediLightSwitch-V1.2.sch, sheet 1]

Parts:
C1: 100uF; EIA7343
C2, C3: 1.0uF; C0805
C4: 22nF; C0805
C5: DNP; C0805
C6: 0.1uF; C0805
D1, D2, D3, D4: LED1206-BOTTOM; LED-1206-BOTTOM
FRAME2: FRAME-LETTER; CREATIVE_COMMONS
JP2, JP3: M04SMD_STRAIGHT_COMBO; 1X04_SMD_STRAIGHT_COMBO
LOGO1, LOGO2: OSHW-LOGOM; OSHW-LOGO-M
R1, R2, R7, R10: 4k7; R0805
R3: 10k; R0805
R4: 0R; R0805
R5, R6, R8, R9: 1k; R0805
TP3, TP5, TP6, TP7, TP8, TP9: TPTP20R; TP20R
TP4: 3v3; TP20R
U1: APDS-9960
U2: HTU21DSMD; HTU21D
U3: PHOTON_SMD
U4: AT42QT1010SOT23; SOT23-6
U$1: LARGE_CAPSENSE

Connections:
3.3V: C3.1, JP2.1, R1.2, R2.2, R3.1, R4.1, TP4.TP, U1.8 (VDD), U2.VDD, U3.24 (3V3); also elsewhere on the board
5V: JP3.4, TP3.TP, U3.1 (VIN); also elsewhere on the board
BATT_MON: U3.8 (A4); also elsewhere on the board
CHARGE_STAT: U3.9 (A3); also elsewhere on the board
D4: TP8.TP, U3.17 (D4)
DAC: TP6.TP, U3.6 (DAC)
GESTURE: R3.2, U1.2 (INT), U3.15 (D2)
GND: C1.C (-), C2.2, C3.2, C6.1, JP2.4, JP3.3, R5.2, R6.2, R8.2, R9.2, TP5.TP, TP9.TP, U1.6 (GND), U2.7 (GND), U2.GND, U3.2 (GND), U3.21 (GND), U4.2 (VSS), U4.6 (SYNC/MODE); also elsewhere on the board
IRLED_DRIVE: U3.12 (A0); also elsewhere on the board
LED1: D1.A, U3.10 (A2)
LED2: D2.A, U3.16 (D3)
LED3: D3.A, U3.7 (A5)
LED4: D4.A, U3.20 (D7)
LIGHT_LEVEL: U3.11 (A1); also elsewhere on the board
unnamed: U1.3 (LDR), U1.4 (LEDK)
unnamed: C1.A (+), C2.1, R4.2, U1.5 (LEDA)
unnamed: D2.C, R5.1
unnamed: D1.C, R6.1
unnamed: JP2.2, U3.23 (!RST)
unnamed: JP2.3, U3.22 (VBAT)
unnamed: R7.2, R10.2
unnamed: R10.1, U$1.P$1
unnamed: JP3.1, U3.4 (RX)
unnamed: JP3.2, U3.3 (TX)
unnamed: C4.2, C5.2, R7.1, U4.3 (SNSK)
unnamed: C4.1, C5.1, U4.4 (SNS)
unnamed: D3.C, R8.1
unnamed: D4.C, R9.1
NEOPIXELS_DIN: U3.5 (WKP); also elsewhere on the board
SCL: R1.1, U1.7 (SCL), U2.SCK, U3.14 (D1); also elsewhere on the board
SDA: R2.1, U1.1 (SDA), U2.DATA, U3.13 (D0); also elsewhere on the board
TOUCH: U3.18 (D5), U4.1 (OUT)
TOUCH_VDD: C6.2, TP7.TP, U3.19 (D6), U4.5 (VDD)

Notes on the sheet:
I2C Pullups
Addr: 0x39
C4 Range: 10-50nF. 10nF no response. 68nF sensitive without touch
Stephen Harrison
1.2
Sparkfun Eagle Library and breakout boards for HTU21D, APDS-9960 & AT42QT1010 used under CC. See Readme.md
Reverse mount LEDs.
LED mounts on base of board with lens going through hole in board to user facing side.
LED Options: Blue LED: Farnell 2290349 (3v3 drop, 20mA, 700mcd) Green LED: Farnell 2217905 (2v1 drop, 20mA 100mcd) Or another 1206 reverse mount LED.
Gesture interrupt active low.
Interrupt active high
Ensure diode protection on daughter board for +5V if supply.
Gesture/Proximity detect
RGB and Light level sense.
Temperature and humidity sense
Top Left
Top Right
Bottom Left
Bottom Right
A3 & DAC not 5V Tol.
Reserved: Second touch pad.
Reserved: Buzzer

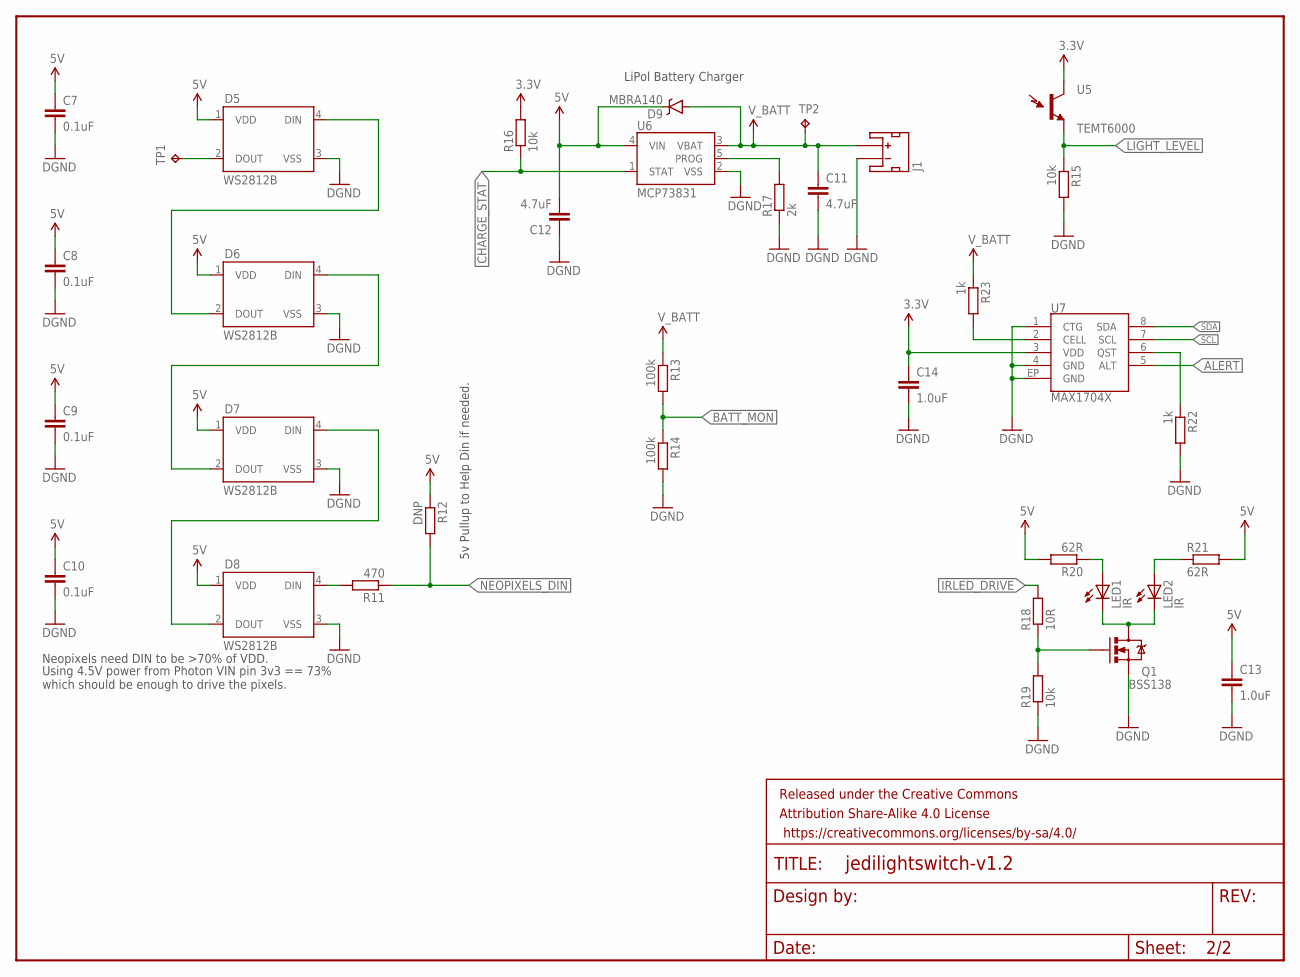
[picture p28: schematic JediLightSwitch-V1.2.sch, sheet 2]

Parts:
C7, C8, C9, C10: 0.1uF; C0805
C11, C12: 4.7uF; C0805
C13, C14: 1.0uF; C0805
D5, D6, D7, D8: WS2812B
D9: MBRA140; SMA-DIODE
FRAME1: FRAME-LETTERNO_PACKAGE; DUMMY
J1: JST_2MM_MALE; JST-2-SMD
LED1, LED2: IR; 1206
Q1: BSS138; SOT23-3; FARNELL 9845330
R11: 470; R0805
R12: DNP; R0805
R13, R14: 100k; R0805
R15, R16, R19: 10k; R0805
R17: 2k; R0805
R18: 10R; R0805
R20, R21: 62R; R0805
R22, R23: 1k; R0805
TP1, TP2: TPTP20R; TP20R
U5: TEMT6000; TEMT6000-SEN
U6: MCP73831; SOT23-5
U7: MAX1704X; TDFN-8

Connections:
3.3V: C14.1, R16.2, U5.COLLECTOR (C1), U7.3 (VDD); also elsewhere on the board
5V: C7.1, C8.1, C9.1, C10.1, C12.2, C13.1, D5.1 (VDD), D6.1 (VDD), D7.1 (VDD), D8.1 (VDD), D9.C, R12.1, R20.2, R21.2, U6.4 (VIN); also elsewhere on the board
ALERT: U7.5 (ALT)
BATT_MON: R13.2, R14.1; also elsewhere on the board
CHARGE_STAT: R16.1, U6.1 (STAT); also elsewhere on the board
GND: C7.2, C8.2, C9.2, C10.2, C11.2, C12.1, C13.2, C14.2, D5.3 (VSS), D6.3 (VSS), D7.3 (VSS), D8.3 (VSS), J1.1 (-), Q1.2 (S), R14.2, R15.2, R17.1, R19.1, R22.2, U6.2 (VSS), U7.1 (CTG), U7.4 (GND), U7.EP (GND); also elsewhere on the board
IRLED_DRIVE: R18.2; also elsewhere on the board
LIGHT_LEVEL: R15.1, U5.EMITTER (E1); also elsewhere on the board
unnamed: Q1.1 (G), R18.1, R19.2
unnamed: R17.2, U6.5 (PROG)
unnamed: LED1.A, R20.1
unnamed: D7.4 (DIN), D8.2 (DOUT)
unnamed: R23.2, U7.2 (CELL)
unnamed: D5.2 (DOUT), TP1.TP
unnamed: D6.4 (DIN), D7.2 (DOUT)
unnamed: D5.4 (DIN), D6.2 (DOUT)
unnamed: D8.4 (DIN), R11.2
unnamed: LED2.A, R21.1
unnamed: LED1.C, LED2.C, Q1.3 (D)
unnamed: R22.1, U7.6 (QST)
NEOPIXELS_DIN: R11.1, R12.2; also elsewhere on the board
SCL: U7.7 (SCL); also elsewhere on the board
SDA: U7.8 (SDA); also elsewhere on the board
V_BATT: C11.1, D9.A, J1.2 (+), R13.1, R23.1, TP2.TP, U6.3 (VBAT)

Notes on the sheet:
Neopixels need DIN to be >70% of VDD.
Using 4.5V power from Photon VIN pin 3v3 == 73% which should be enough to drive the pixels.
LiPol Battery Charger
5v Pullup to Help Din if needed.

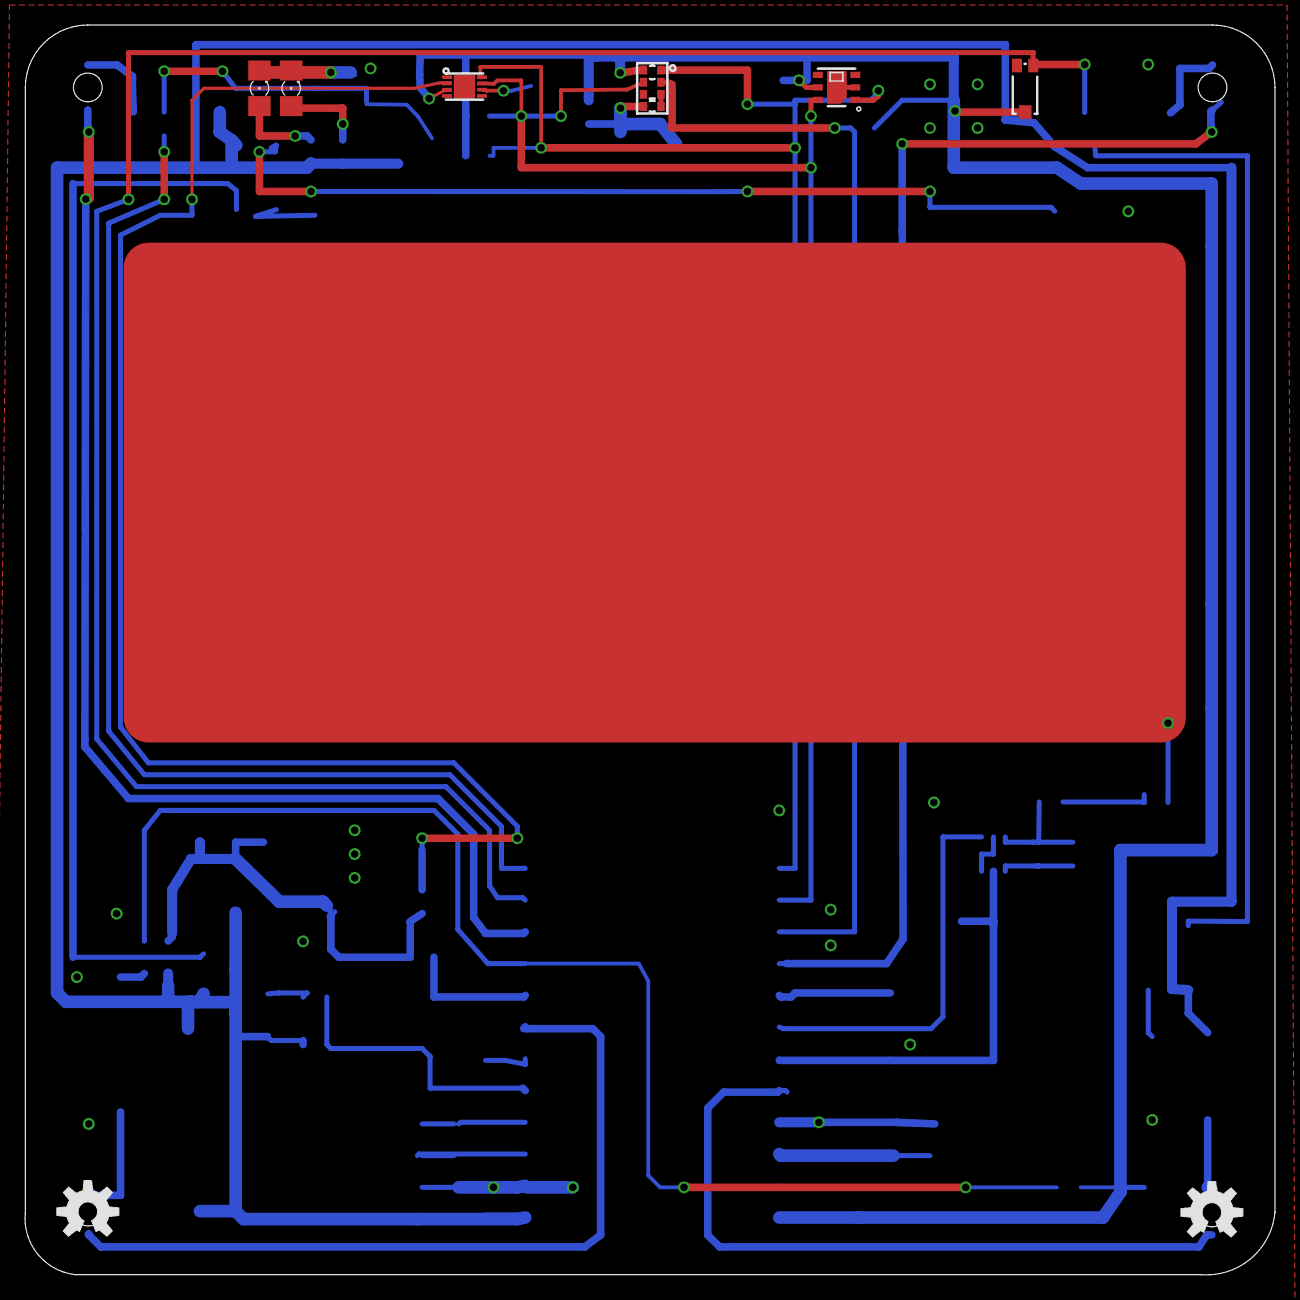
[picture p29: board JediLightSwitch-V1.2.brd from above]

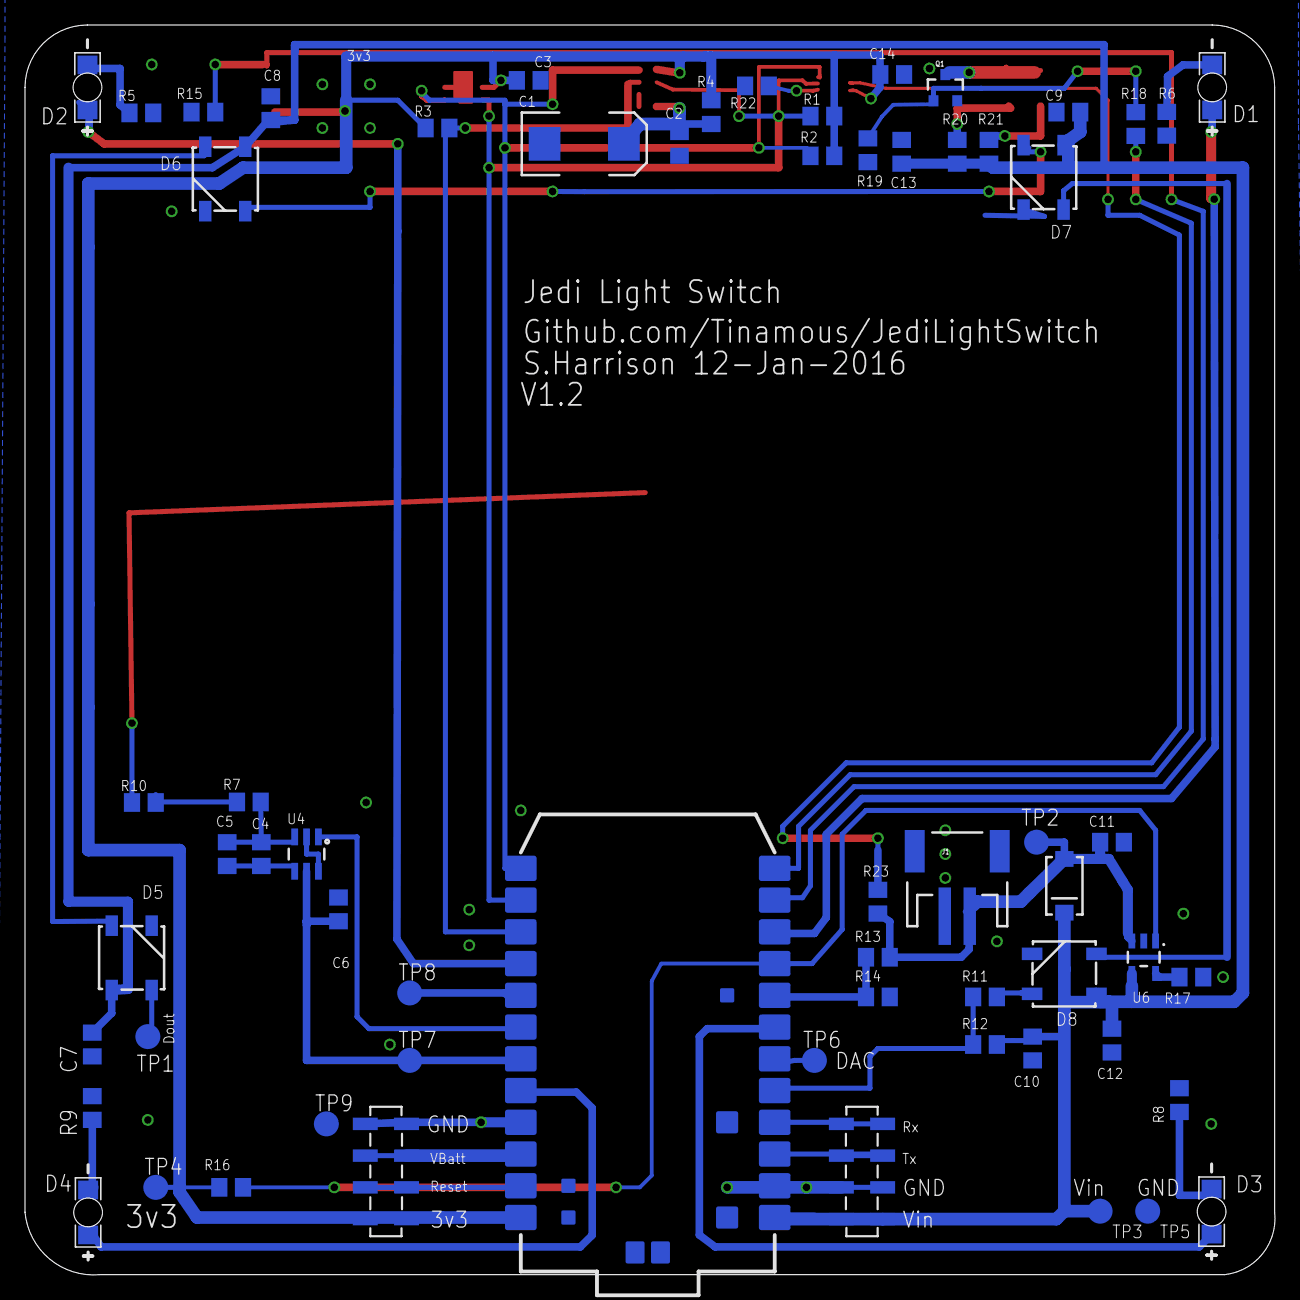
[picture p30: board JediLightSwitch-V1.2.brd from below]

Board: 2 copper layers, 100.0 x 100.0 mm, 73 parts (62 on the bottom side), 46 nets.

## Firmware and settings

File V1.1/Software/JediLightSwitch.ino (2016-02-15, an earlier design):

// This #include statement was automatically added by the Particle IDE.
#include "SenMLBuilder.h"

// This #include statement was automatically added by the Particle IDE.
#include "IrBlaster.h"

// This #include statement was automatically added by the Particle IDE.
#include "LightSensor.h"

// This #include statement was automatically added by the Particle IDE.
#include "LedHandler.h"

// This #include statement was automatically added by the Particle IDE.
#include "PowerManagement.h"

// This #include statement was automatically added by the Particle IDE.
#include "GestureSensor.h"

// This #include statement was automatically added by the Particle IDE.
#include "TouchSensors.h"

// This #include statement was automatically added by the Particle IDE.
#include "EnvironmentSensors.h"

// This isn't neaded but Partile build complains if it's not.
// It's already included in GestureSensor.h
#include "SparkFun_APDS9960.h"

///////////////////////////////////////////////////////////////////////////////////
// 0: V1.0 board (with logo on)
// 1: V1.1 board (2 vertical front sensors, LED in each corner)
// 2: V1.2 board (5 horizontal front sensors)
const int HARDWARE_REV = 2;
///////////////////////////////////////////////////////////////////////////////////

///////////////////////////////////////////////////////////////////////////////////
// Hardware abstraction.
LedHandler* leds;
EnvironmentSensors* environmentSensors;
TouchSensors* touchSensors;
GestureSensor* gestureSensor;
PowerManagement* powerManagement;
IrBlaster* irBlaster;
///////////////////////////////////////////////////////////////////////////////////

///////////////////////////////////////////////////////////////////////////////////
// Particle functions
// Flash the user facing LEDs
int flash(String command);
// Switch on the internal LED to make the box glow.
int glow(String command);
// Turn off User facing LEDs/Internal LED
int off(String command);
///////////////////////////////////////////////////////////////////////////////////

// Build a senml document for publishing
// NB: Max document size for publishing is 255 bytes.
SenMLBuilder senMLBuilder = SenMLBuilder();

// If the lightswitch things it is currently dark.
bool isDark = false;

// Loop counter 
int loopCounter = 0;
int publishMeasurementsCounter = 0;

// If measurements should be taken on the next run through loop.
bool timeToTakeMeasurements = false;

// Measurement timer. Every n seconds.
Timer takeMeasurementsTimer(20000, takeMeasurementsTick);

// ***********************************************************************
// Setup
// ***********************************************************************
void setup() {
    
    setupHAL();

    setupLeds();
    
    setupGestureSensor();
    
    setupTouch();
    
    setupEnvironmentSensors();
    
    setupIrBlaster();
    
    setupParticleFunctions();
    
    //attachInterrupt(D2, interruptHandler, FALLING);
    
    setupComplete();
    
    // Force and an initial measurement reading.
    //timeToTakeMeasurements = true;
}

void interruptHandler() {
    leds->debugLedOn();
}

// Setup the hardware abstraction layer classes.
void setupHAL() {
    if (HARDWARE_REV == 2) {
        leds = new LedHandlerV2();
        gestureSensor = new GestureSensorV2(leds);
        environmentSensors = new EnvironmentSensorsV2(leds);
        irBlaster = new IrBlasterV2();
        touchSensors = new TouchSensorsV2(leds);
        powerManagement = new PowerManagementV2();
    } else {
        leds = new LedHandlerV1();
        gestureSensor = new GestureSensorV1(leds);
        environmentSensors = new EnvironmentSensorsV1(leds);
        irBlaster = new IrBlasterV1();
        touchSensors = new TouchSensorsV1(leds);
        powerManagement = new PowerManagementV1();
    }
    
}

void setupLeds() {
    if (!leds->init()) {
        Particle.publish("Setup", "Leds setup error.");
        RGB.color(255, 0, 00);
    }
}

void setupGestureSensor() {
    if (!gestureSensor->init()) {
        Particle.publish("Setup", "APDS-9960 setup error.");
        RGB.color(255, 0, 00);
    } 
}

void setupEnvironmentSensors() {
    if (!environmentSensors->init()) {
        Particle.publish("Setup", "EnvironmentSensors setup failed.");
        RGB.color(255, 0, 00);
    }
}

void setupIrBlaster() {
    if (!irBlaster->init()) {
        Particle.publish("Setup", "IR Blaster setup failed.");
        RGB.color(255, 0, 00);
    }
}

void setupTouch() {
    if (!touchSensors->init()) {
        Particle.publish("Setup", "Touch sensor setup faield.");
        RGB.color(255, 0, 00);
    }
}

void setupPowerManagement() {
    if (!powerManagement->init()) {
        Particle.publish("Setup", "Power management setup failed.");
        RGB.color(255, 0, 00);
    }
}

// Set-up internet callable Particle functions
void setupParticleFunctions() {
    Particle.function("flash", flash);
    Particle.function("glow", glow);
    Particle.function("off", off);
}

void setupComplete() {
    // Complete setup.
    Particle.publish("Setup", "Jedi Light Switch Set-up complete. V1.2.15");
    
    // Short delay to allow the LEDs to be seen and
    // publishing to happen.
    delay(500);
    leds->ledsOff();
    
    // Start the measurements timer
    takeMeasurementsTimer.start();
}

// ***********************************************************************
// Main Loop
// ***********************************************************************
void loop() {
    
    gestureSensor->checkForGesture();
    touchSensors->checkIfTouched();
    
    if (timeToTakeMeasurements) {
        takeMeasurements();
    }
    
    // Check to see if the light level has changes
    // Uses Gesture sensor and/or environment sensors which are updated 
    // in the background.
    checkLightDarkLevel();

    loopCounter++;
    delay(250);
    leds->debugLedOff();
}

// Called every n seconds by the timer.
// to take light/temperature/humidity measurements and 
// publish them.
// Does not actually take the measurements as it publishes
// and this can cause delays which are undesirable
void takeMeasurementsTick() {
    timeToTakeMeasurements = true;
}

// Called every n seconds by the timer.
// to take light/temperature/humidity measurements and 
// publish them.
void takeMeasurements() {
    
    timeToTakeMeasurements = false;
    
    // Flash the LEDs when measuring to give feedback
    //allLedsOn(); // temp debug to show reading
    //leds->debugLedOn();
    
    // Read the light level every loop but 
    // only publish the update every n times around.
    gestureSensor->readLightLevel(false);
    
    //gestureSensor->readLightColors(publishMeasurements);
    environmentSensors->readTemperatureAndHumidity(false);
    
    environmentSensors->readAnalogLightLevel(false);
    
    powerManagement->readPowerState(false);
    
    // publish the measurements as one block if appropriate and reset the counters
    if (publishMeasurementsCounter > 0) {
        // Start a nice fresh senml document.
        senMLBuilder.begin();
        environmentSensors->appendSenML(&senMLBuilder);
        gestureSensor->appendSenML(&senMLBuilder);
        powerManagement->appendSenML(&senMLBuilder);
        senMLBuilder.publish();
        
        publishMeasurementsCounter = 0;
    }
    publishMeasurementsCounter++;
    
    // Delay to allow the leds to be seen to flash
    delay(250);
    //leds->debugLedOff();
}

// ***********************************************************************
// Check to see if it is light/dark.
// ***********************************************************************
void checkLightDarkLevel() {
    // TODO: Make ambientLightThreshold configurable via particle function.
    
    if (gestureSensor->isDark()) {
        if (!isDark) {
            // Below "Dark" level
            // Enable glowing.
            leds->glow();
        
            Particle.publish("Status", "It is now dark.");
            isDark = true;
        }
    }  else if (gestureSensor->isLight()) {
        if (isDark) {
            // Above "Light" level
            // Disable glowing.
            // TODO: But not if requested via the glow particle.function 
            leds->noglow();
        
            Particle.publish("Status", "It is now light.");
            isDark = false;
        }
        
        return;
    }
}

///////////////////////////////////////////
// Particle Function handles
///////////////////////////////////////////

// Flash the user facing LEDs
int flash(String command) {
    
    for (int i = 0; i<10; i++) {
        leds->ledsOff();
        leds->topLedsOn();
        delay(250);
        
        leds->ledsOff();
        leds->bottomLedsOn();
        delay(250);
    }
    
    leds->ledsOff();
    
    Particle.publish("Status", "Flashed LEDs");
    return 1;
}

// Switch on the internal LED to make the box glow.
int glow(String command) {
    if (command == "on") {
        leds->glow();
        Particle.publish("Status", "Glowing");
        return 1;
    } else if (command == "rainbow") {
        leds->rainbowGlow();
        Particle.publish("Status", "Rainbow Glowing");
        return 2;
    }
    else {
        leds->noglow();
        Particle.publish("Status", "Not Glowing");
        return 0;
    }
    
    Particle.publish("Status", "No command for glow :-(");
    return -1;
}

// Turn off User facing LEDs/Internal LED
int off(String command) {
    
    leds->ledsOff();
    leds->noglow();
    Particle.publish("Status", "LEDs Off");
    return 0;
}

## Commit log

2016-01-09 Initial working version (V1.0)
    [JediLightSwitch-Base.stl, JediLightSwitch-Cover.stl, JediLightSwitch-SlimBase.stl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]
2016-01-09 Updated PCB readme.
2016-01-10 Modified to give bigger gap between base/cover as the fitting was very tight.
    [JediLightSwitch-Base.stl, JediLightSwitch-Cover.stl, JediLightSwitch-SlimBase.stl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]
2016-01-10 Updated Schematic & PCB: * Added 2x extra LEDs for bottom left/right. * Added second capacitor and resistor options to cap sense circuit. * Cap sense chip is now powered by Photon to allow for re-cal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
    Bumped revision of cicuit/board to V1.1
    [JediLightSwitch.brd, JediLightSwitch.sch]
2016-01-12 Version 1.2 of Jedi Light Switch as sent to OSH Park.
    Added:
    * 4x back facing NeoPixes.
    * LiPol interface. Charger and monitor.
    * 2x IR LEDs
    * TEMT6000 light sensor as gesture sensor is very direct
    Re-arranged board top so that all the sensors are in a single row.
    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
    [JediLightSwitch.brd, JediLightSwitch.sch]
2016-01-12 Added V1.2 PCB images as generated by OSH Park
2016-02-01 Updated enclosure.
    Removing old stls.
    Added BuildEnclosures.bat to batch build the various sizes of enclosure.
    [JediLightSwitch-Base.stl, JediLightSwitch-Cover.stl, JediLightSwitch-SlimBase.stl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]
2016-02-01 Added start of sample inlays to go between switch cover and PCB.
2016-02-01 Added PCB eagle files.
    [JediLightSwitch-V1.1.brd, JediLightSwitch-V1.1.sch]
2016-02-01 Added stl's for base/cover.
    [Base-16mm.stl, Base-19mm.stl, Base-25mm.stl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]
2016-02-01 Deleted non-versioned eagle files.
    [JediLightSwitch.brd, JediLightSwitch.sch]
2016-02-01 Removed V1.0 pdf's from this V1.1 branch.
    Updated V1.1 pdf's for the V1.1.1 modification (moved 3v3 rail away from I2C pullups).
    [JediLightSwitch-V1.1.sch]
2016-02-01 Added gitignore to ignore Eagle temp board/schematic files
2016-02-07 Updated resistor values.
    [JediLightSwitch.brd, JediLightSwitch.sch]
2016-02-08 Added minimal option to just give a small frame around the outside.
    [Base-16mm.stl, Base-19mm.stl, Base-25mm.stl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]
2016-02-08 Moved V1.1 files into the V1.1 folder & updated gitignore
    [Base-16mm.stl, Base-19mm.stl, Base-25mm.stl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]
2016-02-08 Moved PCB files into V1.2/PCB folder to match with V1.1 files, removed enclosure design to prevent clashing with V1.1
    [JediLightSwitch-Base.stl, JediLightSwitch-Cover.stl, JediLightSwitch-SlimBase.stl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]
2016-02-08 Deleted old pdfs and renamed V1.2 eagle files to include V1.2
    [JediLightSwitch-V1.2.brd, JediLightSwitch-V1.2.sch]
2016-02-15 Updated enclosure for 1.2 PCB.
    [Base-16mm.stl, Base-19mm.stl, Base-25mm.stl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]
2016-02-15 Added part values
    [JediLightSwitch-V1.2.brd, JediLightSwitch-V1.2.sch]
2016-02-15 Split out functionality into version specific classes for improved encapsulation and readability.
    Works for V1.1 and V1.2 boards. Set HARDWARE_REV = 1 or 2 for the appropriate version.

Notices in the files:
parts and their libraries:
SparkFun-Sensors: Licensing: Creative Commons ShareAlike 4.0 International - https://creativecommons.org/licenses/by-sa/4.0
